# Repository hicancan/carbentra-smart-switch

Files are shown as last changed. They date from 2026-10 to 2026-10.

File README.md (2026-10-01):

# CARBENTRA Switch · 三路智能灯光开关

面向普通照明的三路独立远程通断工程候选。保留本地按键，使用 Wi-Fi 连接 MQTT，蓝牙负责安全配网；计量三路灯具的合计用电。外观参考用户提供的白色圆角三键开关图片，内部结构、电路和固件为独立设计。

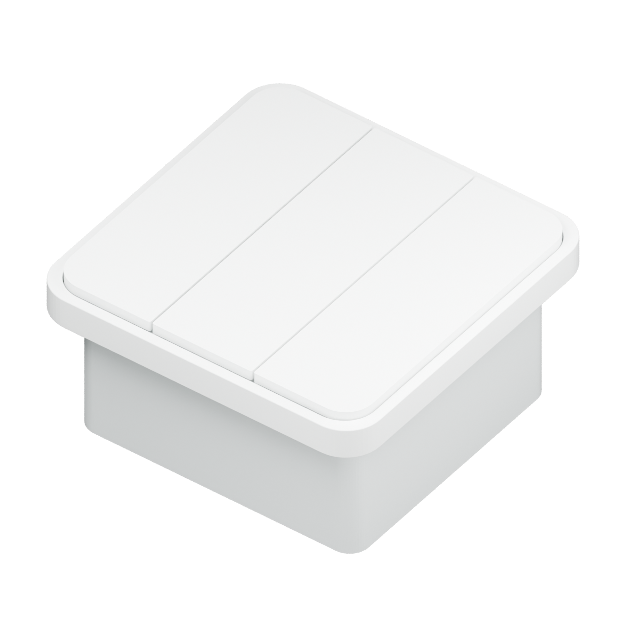
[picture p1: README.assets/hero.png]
Switch 工程外观


## 从这里开始

- **构建验证**：[LOCAL_BUILD.md](LOCAL_BUILD.md)，PowerShell 7 / uv Python 3.12 / MSVC / KiCad 10 / Blender 5.2 / ESP-IDF 5.4.3。
- **改外壳**：`mechanical/` 的可编辑 Blender 源文件与参数化生成脚本
- **改电路**：KiCad 10 打开 `electronics/power.kicad_pro` 或 `electronics/control.kicad_pro`
- **查元器件**：`electronics/bom.csv`、`pinmap.csv`、`mechanical_interface.json`
- **制造与展示**：[GitHub Releases](https://github.com/hicancan/carbentra-smart-switch/releases) 提供 Gerber/钻孔、GLB/STL、图片/PDF/视频与默认禁止吸合的开发固件。
- **继续固件**：[固件说明](firmware/README.md)、[协议与条件](docs/firmware.md)、[实际目标构建报告](firmware/build-report.json)
- **安全修复复验**：[本次固件修复报告](firmware/remediation-report.json)：证书日期配置、实际 ESP32-C3 编译负控与独立 host 证书负控；不代替实物 TLS 握手或现场安全验证
- **了解电气前提**：[电路说明](docs/electronics.md)、[结构说明](mechanical/README.md)

## 已实现的范围

- 三路控制、本地按键防抖、开机先释放、上电OFF；工程构建默认禁止继电器吸合，独立编译放行与逐台commissioning后才允许ON
- 每通道15分钟手动保持、保护/维护/故障守卫，真实本地输入与独立sample序号；网络不能隐式覆盖本地保持
- Wi-Fi 与双向 TLS MQTT 远程命令；时效、序列及幂等处理
- 官方 BLE Security 2 配网，需独立的设备工厂配置；没有内嵌通用密码
- MCP39F511A 串口计量读取、校验与累计能量保存；校准缺失、数据过期或异常时不伪造读数
- 实际 ESP-IDF 5.4.3 / ESP32-C3 目标构建通过，具体结果与源/产物哈希见构建报告

共享设备语义与运行时以 [carbentra-campus-platform](https://github.com/hicancan/carbentra-campus-platform) 的 `packages/iot-contract` 和 `edge` 为唯一实现；lighting-1..3 映射为 relay.1..3，合计电量只计一次。本次 Windows 原生编译、主机回归、ERC/DRC、网络连通、8 mm 隔离与八条主电流路径检查见[验证摘要](verification/local-validation.json)。

可生成的大文件已移出 Git，构建只写指定的外部目录。电路复现边界为原生 KiCad → 严格检查 → 制造输出；旧一次性生成与自动布线工具退入 Git 历史，不承诺重新自动布线得到相同 PCB。

蓝牙在本版本中用于配网，并非另一个直接开关灯协议。计量对象是三路照明合计，不提供单路电量；开关自身待机耗电不在这条分流测量通路内。继电器软件输出状态不等于实际触点或灯具状态的独立回读。

## 尺寸与安装假设

参考图没有确认厂商型号或官方尺寸。本设计提出 86 × 86 mm 面板、9.8 mm 前部突出、74 × 70 × 34 mm 后盒，总包络为 86 × 86 × 43.8 mm。需要根据实际墙腔、螺钉与导线弯曲空间核对，不能当作所有“86底盒”通用安装承诺。

电气方案假设开关盒中具备零线，采用 220–240 V AC、50 Hz 输入。不包含单火线、调光或调色温方案；不需要把灯具回流零线接回该开关盒。

## 使用边界

这是未上电、未安装、未经过实物验证的工程文件。规则检查和成功编译不等同于电气安全、温升、浪涌、EMC、射频、灯具启动冲击或计量精度认证。制造输出不是量产放行文件，需由合格人员完成器件、装配及样机验证。

仅针对普通照明研究，不用于消防应急或其他安全关键照明。远程 OFF 不构成维修隔离；一次保护元件和最终负载能力必须按现场条件验证。

许可证范围见 [LICENSES.md](LICENSES.md)。本地 KiCad 库、SDK、厂商资料继续遵守各自许可；参见 [电路第三方说明](electronics/THIRD_PARTY.md)和[固件第三方说明](firmware/THIRD_PARTY_NOTICES.md)。

本次 Windows 固件与发布回归见 [当前固件验证](verification/current-firmware-validation.json)。打包要求当前来源和实际目标字节一致；历史 CAD/媒体复用独立标注，未重新运行实物、CAD 或渲染验收。

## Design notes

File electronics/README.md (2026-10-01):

# Native editable electronics

Open the control / power `.kicad_pro` projects with KiCad 10.0.5. Schematics, routed boards, rules, local symbol/footprint libraries, BOM, pin maps and mechanical contracts are retained as editable source. These native circuit files are authoritative.

Follow [LOCAL_BUILD.md](../LOCAL_BUILD.md) and `scripts/dev.ps1 -Action electronics -BuildRoot <external-directory>`. The coordinator copies source into a fresh external directory, runs strict ERC/DRC, exports native netlists and independently compares PCB pad connections, then produces schematic PDF, Gerbers, Excellon drills and source-faithful presentation sheets. A nonzero rule check stops the workflow. Generated output and detailed JSON reports live in the build tree and Release bundle.

The export workflow also checks isolated hot/cold copper spacing and eight selected main current paths. These geometrical checks do not establish a load rating or electrical safety certification.

The validated reproducible boundary is native circuit → checks → manufacturing outputs. Earlier one-time ECO, placement-generation and autorouting scripts are retained only in Git history. Their alternate valid routings are not claimed to reproduce the current boards. After deliberate native edits, rerun the whole electronics stage and review the resulting drawings.

Third-party datasheets are linked in `reference-sources.json` and BOM/documentation rather than redistributed. Retained library files preserve their original attribution. See [THIRD_PARTY.md](THIRD_PARTY.md).

Engineering candidate only: no fabricated-board inspection, powered measurements, RF/thermal qualification or manufacturing release is implied.

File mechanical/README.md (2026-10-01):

# SW3 proposed mechanical assembly

This is an independent engineering concept based on the supplied white, rounded three-rocker reference images. No exact manufacturer or model was reliably established. **86 × 86 mm and all housing dimensions are proposed, not manufacturer facts.** The design has no copied logo or certification markings.

## Files

- `carbentra_smart_switch.blend`: neutral, assembled metric source; front is +Z, wall/mounting rear datum Z=0
- `carbentra_smart_switch_animation.blend`: the same real subassemblies with 144 baked frames, 24 fps
- `exports/carbentra_smart_switch.glb`: portable assembly, physical meters
- `exports/*_mm.stl`: structural concept pieces, explicitly millimeter-scaled; not tooling-release files
- `source/build_switch.py` and `source/internal_layout.py`: editable parametric source; component bodies read `electronics/mechanical_interface.json`
- `verification/`: only the minimum file-open, dimensions, gross fit and media checks
- **All images, six views, annotated assembly sheets, SVG/PDF drawings and video are in root `presentation/`**

## Proposed envelope and stack

| Feature | Nominal mm |
|---|---:|
| Face envelope | 86 × 86 |
| Front projection from wall datum | 9.8 |
| Backbox outer envelope | 74 × 70 × 34 |
| Total depth | 43.8 |
| Backbox clear planar cavity | 70 × 66 |
| Main power PCB | 68 × 64 × 1.6, Z -25.6 to -24 |
| Insulating protective partition | Z 0 to +1.8 |
| Isolated control PCB | 76 × 76 × 1, Z +3.2 to +4.2 |
| Momentary rocker main underside / front | Z +7.2 / +9.8 |
| Installer mounting screw centers | X ±30, Y 0; 60 separation |

Suggested initial installation cavity is at least 76 × 72 × 45 mm, but this is **not a compatibility guarantee**. The actual wall box, screw spacing, cable entry and wire bending space must be measured. Do not assume every nominal 86-format wall box accepts this assembly.

The Omron B3U-1000P local switches reach Z +5.8. Molded rocker pushers project 1.4 mm below the main rocker underside; the intended approximately 0.2 mm operating travel still needs button-force and tolerance development.

The real package plan contains three Omron G5Q-1A DC5 relays, RECOM RAC05-05SK/277 isolated supply, MCP39F511A aggregate meter, ISOW7821 isolated interface and ESP32-C3-MINI-1 on the separate cold control PCB. Body envelopes and board coordinates come from the electronics-owned contract, not invented internal parts of the photographed product. Package cosmetic details are simplified; no manufacturer STEP fidelity is claimed.

## Isolation and radio constraints

- Accessible momentary controls are on the isolated cold PCB. A separate insulating partition closes the primary compartment. J3 is on the back of the control board in a modeled isolated-cold protective pocket; both PH8 connectors reserve 10 mm mated height. Eight wires pass sealed individual holes in the pocket floor; the qualified seal/material and harness implementation remain to be developed. The pocket floor top is Z -8.8 and outer bottom Z -10.8. Cable shapes illustrate occupied volume only; the required 5 mm bend radius is not digitally certified
- The installer screws pass through modeled polymer tubes (8 mm OD / 5.5 mm bore), with main PCB side notches and cold PCB clearance holes. Those tubes are a geometry concept, **not proof of reinforced insulation**. Polymer grade, minimum molded wall, tracking resistance, dielectric strength, creepage, clearances and accessible-metal isolation remain safety-review items
- Power board primary/secondary copper zoning, isolation components, fusing, surge protection and electrical slot geometry are owned by the ECAD design. Do not treat the illustration as the copper manufacturing source
- The rim and carrier are nonmetallic. The antenna tip overhangs the control PCB toward +Y; no copper is permitted below its antenna region on any layer. Keep metal, components and installer hardware away per the Espressif antenna guidance; validate the complete wall-box installation, nearby mains wiring and RF behavior on real hardware
- Terminal wire entries are modeled at the recessed backbox upper side. Terminal screw access requires de-energized qualified-installer service with the front/partition removed. A final production design must refine finger protection and service access; never service energized mains
- The selected PSU nominal top is Z -2.2, leaving 2.2 mm physical space below the partition; the maximum MOV envelope leaves 2.0 mm. The rear-mounted C15/C16 capacitors have only 0.6 mm nominal floor clearance and needs tolerance review. Physical space alone does not establish an adequate electrical insulation system

## Status and nonclaims

This is a compact exterior-first engineering proposal with minimum digital checks. It has not undergone mains-powered testing. No load rating, LED inrush capability, energy accuracy, fire rating, insulation certification, RF certification, thermal rating, universal wall-box fit, molding tolerance, button feel or snap-fit life is established. Screw retention, harness termination, terminal access, flame-retardant resin selection, creepage/clearance and standards review need development before any prototype energized testing. Structural STL files are for geometry review and unpowered prototypes only, not a safe live-mains enclosure.

## Reproduction

Use [LOCAL_BUILD.md](../LOCAL_BUILD.md) and `scripts/dev.ps1 -Action mechanical` for geometry/export checks or `-Action render` for presentation. Every action stages source into the specified external build directory. Generated `exports/`, `verification/`, images, PDF and video paths described above exist only in that output tree and the Release bundle, not in the source checkout.

The native assembled and animation `.blend` files stay in this repository. Parameter scripts are editable source. Video uses 37 real 3D assembly states at 1280 × 1280, 144 frames, 24 fps, six seconds, without audio; it is a simulated assembly, not recorded hardware operation. Intermediates remain in the external runtime directory. Source and output hashes record what was checked.

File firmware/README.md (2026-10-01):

# Three-channel smart light switch firmware

ESP32-C3-MINI-1 / ESP-IDF **5.4.3**. Three normally-open relay channels; active-low momentary rocker contacts; secure BLE Wi-Fi provisioning; authenticated MQTT ON/OFF; one isolated MCP39F511A aggregate lighting meter. No dimming, per-channel energy allocation, physical relay feedback or OTA implementation.

The initial image boots all outputs OFF. Physical key sensing works without Wi-Fi, BLE or a broker. Energizing a relay additionally requires the default-OFF build gate and deliberate per-unit factory commissioning; network credentials never grant that release. Local OFF remains available on commissioned units without network service. A key held at boot must first be released. Factory data is intentionally absent from this repository. Missing network credentials disable remote operation; missing or mismatching meter calibration produces null readings.

## Build and host checks

Follow [LOCAL_BUILD.md](../LOCAL_BUILD.md) for the uv + PowerShell + MSVC workflow and pinned ESP-IDF 5.4.3 SDK. The SDK's cJSON compiles with the actual control, meter and command decoder sources. CTest checks commissioning, channel-local holds, maintenance/protection, offline local keys, strict uint64 JSON, replay, meter framing and 2,000 malformed inputs.

See [remediation-report.json](remediation-report.json) for the fresh Linux ESP32-C3
build and TLS remediation evidence. It includes target compile-negative controls
and separately labeled host certificate behavior tests. [build-report.json](build-report.json)
retains the earlier Windows build's original hashes and scope. Development images
and compiler logs are generated outside Git and included in the matching Release.
The build keeps actuation disabled. No board was flashed, calibrated, energized or
physically tested.

## Setup

1. Build the firmware and review [firmware documentation](../docs/firmware.md), the pin map and electronics design. Flash only a safely isolated low-voltage bench target. No live mains commissioning was performed for this deliverable.
2. Prepare a unique device identity, broker client certificate/key, broker CA and per-device BLE Security2 salt/verifier through the operator's approved manufacturing process. Reusable example secrets are not provided. The firmware never prints these values.
3. Store the supplied inputs using `tools/prepare_factory_csv.py` and the official ESP-IDF NVS generator, as documented below. Provision Wi-Fi with Espressif's official BLE provisioning client using Security2, the matching username and unique per-device password. BLE is used for provisioning; MQTT performs remote switching.
4. Configure broker topic ACLs for the device certificate identity. Read its current `state` message, then send a non-retained command with the current boot ID, a strictly increasing decimal sequence and a short boot-relative expiry. Use the acknowledgement to distinguish commanded, duplicate and rejected results. There is no physical-contact verification.
5. A qualified factory process must establish and verify meter calibration and the exact register profile before energy values become available. Firmware does not run automatic calibration or change meter EEPROM/configuration.

See [docs/firmware.md](../docs/firmware.md) for the protocol, factory partition format, calibration units, persistence limitations and official references.

Current Windows firmware/release validation is recorded in `../verification/current-firmware-validation.json`. `remediation-report.json` preserves the earlier Linux run; it is packaged only as historical evidence. See `../LOCAL_BUILD.md` for the source-bound `firmware` action and release checks.

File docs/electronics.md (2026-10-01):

# Smart light switch A: electronics candidate

**Unenergized engineering prototype. Do not install, connect to mains, or treat the Gerbers as a production release.** ERC/DRC and source consistency checks are digital design checks, not product safety, EMC, RF, thermal, LED-inrush, or accuracy certification.

## Scope and interfaces

- Proposed 220–240 V AC, 50 Hz supply **with neutral available in the switch box**; three independent normally-open relay channels
- Wi-Fi remote commands, BLE commissioning, and three local momentary buttons through ESP32-C3-MINI-1-N4X; no dimming
- J1 pins 1–5: **L input, N input, switched L1, switched L2, switched L3**. Lamp neutrals return directly to the supply; they do not need to traverse this switch
- The meter records aggregate lighting energy. It cannot attribute power or Wh to an individual channel, verify a welded relay, or prove a lamp is physically on
- Firmware reports commanded relay state separately from absent physical feedback; uncalibrated, stale, malformed or missing meter readings remain unavailable. See `docs/firmware.md`

## Native deliverables

`electronics/power.kicad_pro`, `.kicad_sch`, `.kicad_pcb`, `.kicad_dru` and corresponding `control.*` are editable KiCad 10 sources. Symbols, footprints and library tables are local and portable. `manifest.json`, `bom.csv`, `pinmap.csv`, and `mechanical_interface.json` describe the same design. The BOM identifies selected major components; commodity passive purchasing substitutions still require voltage, tolerance, temperature, pulse and package review.

- Power PCB: 68 × 64 × 1.6 mm, four copper layers, two open side notches for insulating mounting-screw tubes
- Control PCB: 76 × 76 × 1.0 mm, four copper layers, Ø8.5 mm screw-tube clearances
- Fabrication candidate: `electronics/fabrication/{power,control}/`, including all four copper layers, masks, paste, board outline, Excellon PTH/NPTH drills and placement CSV
- Presentation assets, native schematic PDFs, native SVG plots and drill maps are exclusively under root `presentation/`

No power trace, component or module value is a finished-switch load rating. The **T2 A fuse is a selected protective component, not a certified 2 A product label**. Its time-current curve, prospective fault current, upstream branch protection and enclosure containment must be coordinated in physical qualification.

## Actual circuit

### 1. Protection and cold power

F1 is SCHURTER 3403.0277.23, a time-lag 2 A UMT-H part. RV1 is a thermally protected Littelfuse TMOV14RP275E across the **fused** supply. PS1 is RECOM RAC05-05SK/277, a 5 V/5 W supply selected for reinforced insulation and the manufacturer's OVC III application envelope. A certified component does not certify the assembled wall switch.

The cold 5 V rail supplies three relay coils and a TLV1117LV33DCYR regulator on the control board. The regulator has ceramic input/output capacitors and connected top/inner-layer copper for heat spreading. Wi-Fi peak current, isolated-converter startup, all-coils-on dissipation, brownout behavior and sealed-box temperature rise remain bench tests. No mains neutral is connected to the cold rail.

### 2. Three relay outputs

K1–K3 are Omron G5Q-1A DC5, normally-open contacts driven by AO3400A NMOS devices. Gate series resistors, independent 100 kΩ pull-downs and SS14 coil flyback diodes are implemented. Reset/boot/high-impedance GPIO states therefore bias coils OFF. GPIO0/1/3 control channels 1/2/3.

Generic G5Q contact ratings are not transferred into an LED-load claim. LED driver input capacitance can create severe inrush. Actual lamp types, repetitive make/break endurance, welded-contact faults, arc behavior and temperature rise must be qualified. There is no contact-feedback sensor or safety-disconnect function; the device cannot be used as an isolation switch for servicing.

### 3. Aggregate lighting meter

The current path is:

L_IN → F1 → **H_GND (fused live)** → R7 four-terminal 2 mΩ shunt → H_LOAD → the three relay common contacts → L1/L2/L3.

PS1 branches off before R7, so the intended measured quantity excludes the switch's own electronics consumption. **H_GND is dangerous live potential, not neutral, earth, or accessible digital ground.** Every `H_*` net belongs to that live-referenced meter domain. `C_*` nets belong to the isolated cold domain.

MCP39F511A current input I+ samples the load side of the shunt through 1 kΩ; I− samples its fused-live side through 1 kΩ. V+ receives neutral through four 249 kΩ resistors and a 1 kΩ lower resistor, giving 997:1 nominal attenuation. V− has a matching 1 kΩ return to H_GND. Each channel uses the documented 33 nF input filtering. The 2 mΩ shunt has true separate Kelvin sense pads. Analog decoupling, reference decoupling, RESET/MCLR pull-ups and the COMMONA-to-COMMONB link are present; unused mandatory-NC pins stay floating. The optional external crystal is not fitted; the internal oscillator must be accounted for by the verified factory profile.

For positive lamp consumption both input waveforms have matching negative polarity relative to fused live, yielding positive imported active power. At 2 A, nominal shunt signal is 4 mV RMS, not mains common mode applied to an ADC pin. Validate polarity with a known resistive load and then a nonlinear LED load. Calibration must verify the ADC gain and profile, voltage/current/power/energy scales, frequency, offset and temperature behavior. This design makes **no measured-accuracy claim** and does not rely on zero-calibration defaults.

### 4. Reinforced meter bridge

U3 is **ISOW7821DWER**, a two-direction digital isolator with integrated isolated power. Cold 3.3 V enters VCC/GND1. SEL is tied to hot GND2 for a 3.3 V isolated output. UART idle-high default is intentionally selected by the non-F device variant. The manufacturer's specified working insulation voltage is distinct from its short-duration withstand test; the selected part lists 1000 V RMS working insulation and >8 mm package clearance/creepage.

The local footprint follows the manufacturer's **HV/isolation pad option**, 9.75 mm row-center spacing and 1.65 mm pad length, leaving 8.1 mm between facing copper lands. Bulk input capacitance exceeds the isolated-side output capacitance by more than 100 µF. The hot and cold grounds are not joined, including through the harness, programming pads or inner layers.

### 5. Radio and local control

U1 is ESP32-C3-MINI-1-N4X. GPIO4/5/6 are active-low local buttons, each with external 10 kΩ pull-up and 10 nF capacitor. GPIO7 is isolated-meter UART RX; GPIO10 is TX. GPIO2/8/9 boot straps are not used to drive relays. EN has external pull-up and capacitor. Service pogo pads expose cold ground, 3.3 V, EN, BOOT, UART0 and native USB signals; no USB connector or mains-referenced debug port is exposed to the user.

The module uses the manufacturer's 53-pin land pattern, a top-edge antenna overhang, and an all-layer copper exclusion below the antenna area. The enclosure carrier is polymer. RF matching through the actual plastic/rocker stack, conducted/radiated coexistence, range, interference and regulatory testing remain unperformed. Do not infer radio performance from renderings.

### 6. Cold harness and assembly

J2 and J3 are keyed JST PH 8-way connectors with the same pin map:

1. C_5V
2. C_GND
3. C_3V3
4. C_RELAY1
5. C_RELAY2
6. C_RELAY3
7. C_UART_TX
8. C_UART_RX

J3 is on the control board's **bottom** face, with a local cold-side pocket through the solid partition. The mechanical file budgets the mated connector, not just the bare header. C15/C16 are on the power board rear face and have only 0.6 mm nominal rear-floor clearance; lead trimming, capacitor tolerances, board bow and assembly stack-up must be checked. The 17 major package envelopes in `mechanical_interface.json` are maximum or conservative bodies, not detailed vendor STEP models.

## Insulation assumptions and limits

The final mains spacing assumption is **220–240 V AC nominal, overvoltage category III, 4 kV rated impulse, pollution degree 2, altitude ≤2000 m, uncoated FR4**. The initial 2 mm routing screen was not a justified fixed-installation qualification and is superseded. Native custom rules now require **3 mm** between raw input line, the unattenuated neutral or a switched output and other hot copper that may sit at full mains differential. Hot-domain 3.3 V circuitry retains a 0.2 mm low-voltage rule; graded divider nodes and certified component internals are not blindly treated as independent full-mains conductors.

The whole hot-to-cold PCB copper target is **8 mm**. The router enforces it on the XY projection across every copper layer, and a separate conservative geometric checker covers pads, tracks, vias and otherwise unconnected isolator-side leads. This is stronger than only comparing same-layer copper. It does not assess 3D paths around relay bodies, solder contamination, creepage over supports, screws, wiring, enclosure seams, pollution, material CTI, fire containment or solid-insulation thickness. The final product standard and its applicable creepage/clearance rules still require qualified review. No conformal-coating credit is assumed.

The primary basis is TI's *Demystifying Clearance and Creepage Distance for High-Voltage End Equipment*, especially its IEC 60664-1 4 kV example and altitude treatment. Required creepage also depends on actual working voltage and material group; specify and verify laminate CTI rather than assuming every FR4 grade is equivalent.

## Verification and reproduction

Machine-readable evidence is in `electronics/verification/`:

- Both schematics: actual KiCad ERC output
- Both boards: actual KiCad DRC output, including unconnected-item lists
- `validation.json`: all native schematic nodes compared with PCB pad nets, separate by board, and eight-pin cold harness agreement
- `isolation_xy.json`: independent all-layer conservative hot/cold geometry check
- `load_paths.json`: native connectivity of all eight main lamp-current paths after removing every trace narrower than 1.2 mm and every via smaller than 1.6 mm. The fuse-to-shunt path is an explicit current trunk; narrow hot-reference branches do not carry the intended lamp current. This is no temperature-rise, surge or load-rating validation
- `presentation.json`: SHA-256 of native files used for unchanged-source SVG/PNG generation

Follow [LOCAL_BUILD.md](../LOCAL_BUILD.md) and run the PowerShell electronics stage. It checks authoritative native sources and writes all exports to an explicit external build tree. One-time circuit-generation/autorouting scripts were retired to Git history. The report filenames listed above exist in that generated tree or Release bundle. No hardware is energized.

### Manufacturing candidate notes

Suggested stack-ups (fabricator must approve dielectric construction and tolerances):

- Power 1.60 mm: F.Cu 70 µm / prepreg 0.20 mm / In1 35 µm / core 0.99 mm / In2 35 µm / prepreg 0.20 mm / B.Cu 70 µm
- Control 1.00 mm: F.Cu 35 µm / prepreg 0.18 mm / In1 18 µm / core 0.534 mm / In2 18 µm / prepreg 0.18 mm / B.Cu 35 µm
- Fine-pitch meter escape uses 0.13 mm tracks and 0.45/0.20 mm via diameter/drill. Ordinary routing is wider. Main candidate current routes use 1.2 mm tracks and, where needed, 1.6/0.8 mm vias; these dimensions do not establish a load rating
- Relay and terminal PTH lands are 2.0 mm on 1.3 mm drills; verify the 0.35 mm nominal annulus against hole and registration tolerances
- Copper masks and inner-layer clearances must survive fabricator CAM review. The board outlines include open power-board mounting notches; do not substitute plated mounting holes
- No soldermask, coating, component approval or fuse value is a substitute for complete end-product qualification

## Primary references

- [Microchip MCP39F511A datasheet](https://ww1.microchip.com/downloads/en/DeviceDoc/MCP39F511A-Data-Sheet-20006044A.pdf), pin table, application circuit, protocol and calibration
- [Microchip ADM00667 reference board](https://ww1.microchip.com/downloads/aemDocuments/documents/OTH/ProductDocuments/UserGuides/MCP39F511A-Demo-Board-User-Guide-50002770A.pdf)
- [TI ISOW7821 datasheet](https://www.ti.com/lit/ds/symlink/isow7821.pdf), insulation table, HV land pattern and input bulk capacitance guidance
- [RECOM RAC05-K/277 datasheet](https://recom-power.com/pdf/Powerline_AC-DC/RAC05-K_277.pdf)
- [Omron G5Q datasheet](https://components.omron.com/sites/default/files/datasheet_pdf/J155-E1.pdf)
- [Espressif ESP32-C3-MINI-1 datasheet](https://documentation.espressif.com/esp32-c3-mini-1_datasheet_en.pdf)
- [Vishay WSK2512 datasheet](https://www.vishay.com/docs/30108/wsk2512.pdf)
- [SCHURTER UMT-H datasheet](https://www.schurter.com/en/datasheet/typ_UMT-H.pdf)
- [Littelfuse TMOV datasheet](https://www.littelfuse.com/assetdocs/varistors-tmov-datasheet?assetguid=bd475732-1071-4352-b8aa-f78b0007eb05)
- [TI TLV1117LV datasheet](https://www.ti.com/lit/ds/symlink/tlv1117lv.pdf)
- [Omron B3U datasheet](https://components.omron.com/us-en/system/files/2023-01/datasheet_pdf/A162-E1.pdf)
- [TI clearance and creepage design seminar](https://www.ti.com/lit/ml/slup419/slup419.pdf)

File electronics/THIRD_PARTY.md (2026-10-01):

# Component and CAD library attribution

Local stock KiCad symbols and footprints originate from the KiCad libraries:
- https://gitlab.com/kicad/libraries/kicad-symbols
- https://gitlab.com/kicad/libraries/kicad-footprints

KiCad library content uses CC BY-SA 4.0 with the KiCad Libraries Exception: https://www.kicad.org/libraries/license/ . Local library identifiers and existing attribution are retained. Project-level hardware licensing does not overwrite the library license or exception.

Custom package outlines implement dimensions from manufacturer drawings. The BOM, pin map and docs/electronics.md identify selected parts and primary datasheets. Manufacturer names identify components, not endorsement or certification. Vendor PDFs/HTML snapshots are no longer redistributed: reference-sources.json preserves their original hashes and source links.

Firmware SDK/runtime notices are in ../firmware/THIRD_PARTY_NOTICES.md. No production credentials or private manufacturer application are provided.

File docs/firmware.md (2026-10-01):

# Firmware and remote-control contract

## Implemented scope

Three independent lighting ON/OFF channels use normally-open relay drives. Three active-low, momentary local contacts toggle their corresponding commanded state after35ms of stable debounce. The contact must be released before its first accepted press after reboot. Maintained/latching rocker contacts need a different local-control policy and are not assumed by this implementation. Offline switching does not depend on network initialization. Reset starts all outputs OFF; no previous ON state is restored.

Wi-Fi carries authenticated MQTT control and state. BLE provides Espressif's official Wi-Fi provisioning service using Security2 (SRP6a and AES-GCM), with per-unit salt/verifier loaded from factory NVS. Security0/1 are disabled; no plaintext provisioning fallback or shared password is compiled in. BLE stops after successful provisioning. Changing provisioned Wi-Fi requires a deliberate service operation on the Wi-Fi NVS partition; the command protocol has no remote credential-reset or factory-reset operation.

The three logical switch channels share one aggregate meter covering the sum of their lighting loads. Future campus integration must register three controllable channels plus one parent aggregate energy boundary, without fabricating per-channel energy or counting the aggregate three times. The shared campus Edge adapter maps physical channel IDs lighting-1..3 to canonical relay.1..3 and preserves the single aggregate energy boundary.

## Cold-domain GPIO contract

| Function | ESP32-C3 GPIO | Electrical interpretation |
| --- | ---: | --- |
| Relay1 / Relay2 / Relay3 | 0 / 1 / 3 | Active-high NMOS drives, external100k pulldowns |
| Key1 / Key2 / Key3 | 4 / 5 / 6 | Active-low, external10k pullups and10nF |
| Meter UART RX / TX | 7 / 10 | UART1,9600baud,8N1, isolated channel |
| Reserved boot straps | 2 / 8 / 9 | No application output use |
| USB | 18 / 19 | Reserved |
| Service UART0 | 20 / 21 | Console; firmware does not log secrets |

GPIO latch levels are cleared before enabling output direction. External pulldowns cover reset/boot-ROM intervals. Software state and an electrical GPIO request do not prove relay-contact closure, load current or lamp illumination. Acknowledgements explicitly have `physical_verification:false`; per-channel state has `physically_verified_on:null`.

The MCP39F511A and its analog input circuit are in the hot mains domain. UART crosses the TI ISOW7821 isolation boundary; its isolated supply powers the meter side. The cold controller has no isolation-readiness GPIO and cannot certify insulation, creepage, clearance, relay inrush suitability or safe mains conditions. Calibration/readback only addresses measurement configuration. Firmware is not a substitute for the electronics safety review or physical commissioning.

## MQTT wire protocol

All connections use `mqtts://hostname[:port]`, a supplied CA trust anchor, server-hostname validation and a supplied client certificate/private key. Firmware rejects insecure MQTT URIs and never enables skip-CN checks. Broker ACLs must bind the client identity to its own namespace; authenticated controller clients may publish only to the intended device command topics. SNTP establishes usable wall time for certificate checks before MQTT starts. Command freshness uses a boot-relative clock and does not trust an arbitrary controller wall clock.

Both `sdkconfig.defaults` and the maintained `sdkconfig` require
`CONFIG_MBEDTLS_HAVE_TIME=y` and `CONFIG_MBEDTLS_HAVE_TIME_DATE=y`.
`main/tls_policy.h`, compiled in the actual network translation unit, rejects
missing ESP-IDF options, missing effective mbedTLS time/date macros, or insecure
TLS verification. The target coordinator checks the generated configuration too.

**Time-source threat boundary:** the current bootstrap uses unauthenticated SNTP
(`pool.ntp.org`) and waits for a wall clock at least 2025-01-01. This is a plausibility
gate, not authenticated time or rollback protection. Date validation is against
that system clock; an attacker able to manipulate SNTP can affect certificate
validity decisions. CA and hostname checks remain required, but they do not
authenticate the SNTP clock. Deploy only where that time-source/network assumption
is acceptable; a hostile-time threat model requires a separately reviewed signed
time/bootstrap design before release. Switch does not inherit Plug's signed-time
implementation. No missing-time or date-check-disabled fallback is provided.

Topics:

- `carbentra/switch/<device_id>/command`: controller→device, QoS1, **not retained**
- `carbentra/switch/<device_id>/ack`: device→controller, QoS1, not retained
- `carbentra/switch/<device_id>/state`: device→controller, latest retained snapshot every2s while connected
- `carbentra/switch/<device_id>/availability`: retained online/offline, MQTT last will

A command is an object with exactly these six properties. The example values are illustrative protocol data, not executable commissioning instructions:

```json
{"id":"request-42","boot_id":"0123456789abcdef0123456789abcdef","seq":"42","channel":2,"on":true,"expires_uptime_ms":"125000"}
```

`boot_id` must equal the current state message's32-hex-character boot ID. Firmware obtains fresh128-bit random data from the SDK's explicitly enabled boot-time entropy source before Wi-Fi starts. `seq` and `expires_uptime_ms` are unsigned decimal strings, avoiding JSON double precision loss. Channel is the integer1,2 or3; on is an actual boolean. ID accepts1..48 ASCII alphanumerics, hyphens and underscores. Maximum payload768bytes. Unexpected/duplicate fields, embedded NUL, malformed fragments, invalid types, retained commands and oversized payloads cannot actuate a relay.

Expiry must be strictly after current uptime and at most30s ahead. Controllers should obtain fresh uptime from state and allow transport latency. Sequences increase globally per device boot; coordinate multiple controller clients through one sequence allocator. The last16 accepted command IDs are cached. An identical retry returns `duplicate` without reapplying the output, even if a local key subsequently changed it. Reusing an ID with different content returns `id_conflict`. An evicted old sequence is still rejected. New boot IDs invalidate commands from earlier sessions; the first command in a boot can start at sequence1. No acknowledgement claims measured physical success.

Example acknowledgement fields are device_id, boot_id, id, seq, channel, result, uptime_ms and physical_verification:false. Results are commanded, duplicate, invalid_command, wrong_boot, expired, stale_sequence or id_conflict. A malformed request without a valid ID may receive an invalid_command acknowledgement without id/seq/channel. Rejected retained/oversized/wrong-topic input is discarded. The next state snapshot reports all three current commanded states.

## Meter parsing and calibration

The driver implements MCP39F511A SSI requests:0xA5 header, complete-frame byte count, big-endian address pointer,0x4E register read, and modulo256 sum checksum. A read response must have0x06 ACK, exact count, complete payload and valid checksum. Register data is little-endian. Read blocks never exceed32data bytes.0x15 NAK,0x51 checksum failure, bad lengths, truncation and timeouts cannot become valid samples. The documented unframed0x5A identification probe must return0x15,0x04 before the factory profile is trusted.

Measurement reads cover0x0002..0x001D and import/export active counters0x001E..0x002D. Active power direction comes from System Status SIGN_PA, rather than treating the unsigned magnitude as signed. There is no per-channel energy estimate. UART is polled about once per second; values become unavailable after failure or a5s freshness limit.

A factory calibration record contains an immutable per-unit calibration ID, verified output-unit scales and exactly146bytes from registers0x0050..0x00E1. Firmware compares the full snapshot at startup and every60s, and requires AC mode, live ADCs, energy accumulation enabled, two-wire operation and9600baud. A mismatch, missing record or wrong device identity yields null physical values. The record must be captured after the qualified process has set the correct current polarity,50Hz calibration/reference and gain/range values, saved them and verified readback. The final electronics reference uses a Vishay WSK25122L000FEA2mΩ four-terminal shunt,997:1 voltage divider and the internal4MHz oscillator. Current and voltage input polarities are both negative for positive import in the selected topology, so their product must be verified positive by the fixture. The PSU branch precedes the shunt and is excluded from aggregate lighting energy. These analog values are not hardcoded as unverified firmware conversion constants. Factory default values or the datasheet's nominal resolution are not a calibration result.

Scale fields are positive integer microvolts per voltage count, microamps per current count, milliwatts per active-power count and milliwatt-hours per energy count. Their accepted range is1..1,000,000. The datasheet describes a default1mWh energy step; the actual record must confirm the configured system. The firmware performs no calibration/configuration writes or energy-counter EEPROM writes. No accuracy percentage or regulatory energy-billing suitability is claimed.

## Persistent energy semantics

The firmware adds only observed, monotonic import-counter deltas with known scale. It does not integrate estimated power or invent energy across reboot, lost communication, counter rollback or rejected jumps. The first sample after each such interruption establishes a new baseline. An internal50kW plausibility ceiling rejects corrupted jumps; it is not a hardware load or relay rating.

Known energy is checkpointed in a separate `energy` NVS partition every60s using a versioned binary format, profile fingerprint and CRC32. After an unexpected power loss, up to60s of newly accumulated known energy can be absent from the saved lower bound, in addition to unknown boot/gap intervals. Telemetry labels it `energy_quality:"partial_lower_bound"`, includes unknown_intervals and checkpoint_interval_seconds, and represents exact known_energy_wh as a decimal string. Missing calibration/storage integrity yields null. A valid measured zero is allowed only within this qualified known-energy context.

A corrupt checkpoint or changed calibration fingerprint is not silently erased or assigned to a new meter. Energy accumulation is disabled pending a deliberate service workflow that archives prior records and provisions a new energy epoch. NVS initialization failures do not erase data automatically. Storage failures are exposed by persistent_storage_ok:false. The flash endurance/checkpoint interval must be validated for the physical product's required service life.

## Factory data and setup

The custom4MiB partition table allocates Wi-Fi NVS, a read-only-by-application `factory` NVS partition, a2.5MiB app slot, and separate energy NVS. It has no OTA partition. Credentials are absent from the source tree. The factory namespace is `switchcfg` (9characters); energy namespace is `energy`.

Prepare a private JSON specification outside Git with device_id, mqtt_uri and paths to prov_salt (16binary bytes), prov_verifier (384binary bytes), ca_pem, client_cert and client_key. Use unique SRP credentials and a unique broker client identity for every device. Espressif's official `tools/esp_prov/esp_prov.py` supports Security2 credential generation through an operator-controlled manufacturing process; this deliverable did not generate or provision credentials. Do not place passwords in shell history or logs.

Optional `calibration` contains id, profile_file and voltage_uv/current_ua/power_mw/energy_mwh. Omit it for uncalibrated logic bring-up; physical values will remain null. The preparation helper validates file lengths and profile fields, then emits a private CSV containing file references. It does not generate secrets, flash, connect or transmit.

```sh
python firmware/tools/prepare_factory_csv.py /private/unit-spec.json /private/unit-factory.csv
python "$IDF_PATH/components/nvs_flash/nvs_partition_generator/nvs_partition_gen.py" generate \
  /private/unit-factory.csv /private/unit-factory.bin 0x10000
```

The factory binary must be installed at its explicit partition offset0x10000 by an authorized technician, together with the ordinary SDK build outputs. An ordinary `idf.py flash` does not supply factory credentials. Use official Espressif provisioning clients with Security2 and the matching username/password supplied separately to the owner; no credential-bearing QR is emitted to logs. Broker ACLs and certificate issuance belong to the operator, not this repository.

The default bench build does not burn security eFuses, enable irreversible Secure Boot, or provision flash-encryption keys. Factory credentials are therefore physically readable unless a product-specific encrypted-NVS/flash-encryption and debug-access policy is provisioned. Network transport/authentication is implemented; physical extraction resistance is not claimed by this default build. Deploying that security policy requires the appropriate authorized manufacturing procedure.

## Verification and remaining physical work

Host regression groups compile the real C core and cJSON decoder with strict warnings and CTest on Windows. They cover offline keys/held-key boot, debounce, all channel bounds, maximum64-bit sequence and overflow, replay/idempotency/conflicts, old-boot rejection, expiry, official meter request bytes, little-endian decoding, checksum/length errors, import/export sign, missing intervals, monotonic delta handling, checkpoint corruption/profile mismatch, strict JSON and2,000 malformed-input cases. Current Windows evidence does not claim UBSan or LeakSanitizer. Earlier Linux sanitizer results remain historical.

Target build status is recorded in firmware/build-report.json when compilation completes. No ESP32 board, relay, lamp, radio link, broker deployment, live credentials or mains meter was exercised here. Hardware UART timing, polarity, real calibration, RF coexistence, power-loss behavior, contact/inrush performance and physical safety remain bench/engineering validation tasks. Generated images and presentation assets are owned by the root presentation workflow, not firmware.

The TLS remediation has three separate verification levels: the maintained
`tests/check_tls_config.py` regression checks both configuration files and compiles
positive/negative fixtures against the actual guard; `tests/check_certificate_policy.py`
exercises a separately compiled **host** mbedTLS verifier with valid, expired,
not-yet-valid, wrong-CA and wrong-hostname synthetic certificates; a pinned ESP-IDF
target build/real MQTT handshake remains a separate gate. The host library's date
behavior must never be reported as ESP-IDF target behavior. Existing checked-in
build/source manifests describe their original source hashes and predate this
remediation until a new pinned target build is recorded.

## Primary references

- [ESP-IDF5.4.3 ESP32-C3 documentation](https://docs.espressif.com/projects/esp-idf/en/v5.4.3/esp32c3/index.html)
- [ESP-IDF5.4.3 provisioning example/source](https://github.com/espressif/esp-idf/tree/v5.4.3/examples/provisioning/wifi_prov_mgr)
- [ESP-IDF5.4.3 MQTT client](https://docs.espressif.com/projects/esp-idf/en/v5.4.3/esp32c3/api-reference/protocols/mqtt.html)
- [MCP39F511A datasheet DS20006044A](https://ww1.microchip.com/downloads/aemDocuments/documents/OTH/ProductDocuments/DataSheets/MCP39F511A-Data-Sheet-20006044A.pdf), sections4,5.6,6and9
- [MCP39F511A demonstration-board user guide](https://ww1.microchip.com/downloads/aemDocuments/documents/OTH/ProductDocuments/UserGuides/MCP39F511A-Demo-Board-User-Guide-50002770A.pdf)

## Classroom control upgrade (2026-10-01)

The six-property command remains unchanged. A genuine debounced local key press records its channel, event sequence, uptime and result, and establishes a channel-local manual hold (default 900,000 ms; factory bounds 1..3,600,000 ms). Commands to another channel are independent. Remote ON and OFF are rejected during manual hold, maintenance or a protected channel policy. No remote override flag is accepted. Hold expiry permits future commands but does not itself switch a relay. Exact accepted retries still return duplicate without replaying the action.

Protected channels reject automation while retaining physical local control. Maintenance blocks energizing and forces all commanded states OFF. A GPIO write error latches a software fault and requests all outputs OFF; this does not prove mains disconnection. No electronic overcurrent/overtemperature protection or independent feedback sensor has been invented. Physical protection and qualification remain separate release requirements.

CONFIG_CARBENTRA_SWITCH_ALLOW_ACTUATION defaults OFF. The application also requires explicit per-unit factory commissioned=true before any local or remote ON. Factory values maintenance, protected_mask (bits0..2) and manual_hold_ms are read once at boot; missing values use safe defaults. Merely supplying BLE/MQTT credentials, calibration data or compiling this source does not commission hardware. No release build enabling actuation is produced here.

State adds schema_version=1, device_type=smart_switch and sample_seq (monotonic uint64 decimal string, distinct from last_seq command replay counter). Each state publication gets a sequence; boot_id separates restarts. Each channel carries channel_id lighting-1..3, control_mode auto/manual/maintenance/protected, manual_hold_until_uptime_ms, commanded_on, and physically_verified_on=null with feedback_quality=unavailable_no_independent_sensor. Root fields include actuation_enabled, fault_latched, maintenance, protected_channel_mask and last_local_input {channel,event_seq,uptime_ms,pressed,result}. Event sequence 0 means no press observed. A periodic snapshot does not turn a retained local-input record into a new event; consumers deduplicate by boot_id/event_seq.

Additional rejection results: manual_hold, maintenance, protected, not_commissioned, fault_latched. Aggregate energy remains a partial lower bound and must not be allocated to individual channels.

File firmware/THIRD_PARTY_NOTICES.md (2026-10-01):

# Build and binary component notices

The target is built against ESP-IDF v5.4.3 commit ea1c174c1cbb7348bd8ba0ff1eb306246938dd80. The SDK and recursive submodules remain external tool installations. The exact SDK source is available at https://github.com/espressif/esp-idf/tree/ea1c174c1cbb7348bd8ba0ff1eb306246938dd80 . Preserve the SDK's component licenses when rebuilding or redistributing an image.

Bundled license texts in licenses/ cover ESP-IDF (Apache-2.0), cJSON (MIT), Mbed TLS (Apache-2.0), Apache NimBLE with NOTICE, TinyCrypt (BSD), lwIP (BSD), FreeRTOS (MIT), and the individual Newlib runtime notices. The Espressif Wi-Fi, PHY, coexistence and ESP32-C3 Bluetooth library licenses are copied verbatim from the pinned SDK; those libraries are not project-owned source.

Compiler runtime portions remain covered by their own notices and the GCC Runtime Library Exception. This ledger records the principal directly used components, not a formal exhaustive licensing audit. SDK subcomponents retain their SPDX headers and original source notices. Project-level licenses do not replace them.

Development firmware has relay actuation disabled. No private key, client certificate, Security2 secret, calibration record or per-unit commissioning record is included. Public synthetic test fixtures must not be used as production credentials.

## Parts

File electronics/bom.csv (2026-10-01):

Reference | Board | Value | Manufacturer part / specification | Footprint | Primary source | Side
J1 | power | L N L1 L2 L3 | Phoenix Contact MKDS 1,5/5-5,08 | TerminalBlock_Phoenix:TerminalBlock_Phoenix_MKDS-1,5-5-5.08_1x05_P5.08mm_Horizontal | https://www.phoenixcontact.com/en-us/products/pcb-terminal-block-mkds-15-5-508-1715750 | F
F1 | power | T2A 277VAC / 1500A BC | SCHURTER 3403.0277.23 | Switch:UMT_H | https://www.schurter.com/en/datasheet/typ_UMT-H.pdf | F
PS1 | power | RAC05-05SK/277 | RAC05-05SK/277 | Switch:RAC05_05SK_277 | https://recom-power.com/pdf/Powerline_AC-DC/RAC05-K_277.pdf | F
RV1 | power | TMOV14RP275E | Littelfuse TMOV14RP275E (thermal protected) | Switch:TMOV14 | https://www.littelfuse.com/products/overvoltage-protection/varistors/thermally-protected/tmov | F
K1 | power | G5Q-1A DC5 | G5Q-1A DC5 | Relay_THT:Relay_SPST_Omron-G5Q-1A | https://components.omron.com/sites/default/files/datasheet_pdf/J155-E1.pdf | F
Q1 | power | AO3400A | AO3400A | Package_TO_SOT_SMD:SOT-23 | https://www.aosmd.com/sites/default/files/res/datasheets/AO3400A.pdf | F
R1 | power | 100R | 0603 1% 100R | Resistor_SMD:R_0603_1608Metric |  | F
R4 | power | 100k | 0603 1% 100k | Resistor_SMD:R_0603_1608Metric |  | F
D1 | power | SS14 | SS14 | Diode_SMD:D_SMA | https://www.vishay.com/docs/88746/ss12.pdf | B
K2 | power | G5Q-1A DC5 | G5Q-1A DC5 | Relay_THT:Relay_SPST_Omron-G5Q-1A | https://components.omron.com/sites/default/files/datasheet_pdf/J155-E1.pdf | F
Q2 | power | AO3400A | AO3400A | Package_TO_SOT_SMD:SOT-23 | https://www.aosmd.com/sites/default/files/res/datasheets/AO3400A.pdf | F
R2 | power | 100R | 0603 1% 100R | Resistor_SMD:R_0603_1608Metric |  | F
R5 | power | 100k | 0603 1% 100k | Resistor_SMD:R_0603_1608Metric |  | F
D2 | power | SS14 | SS14 | Diode_SMD:D_SMA | https://www.vishay.com/docs/88746/ss12.pdf | B
K3 | power | G5Q-1A DC5 | G5Q-1A DC5 | Relay_THT:Relay_SPST_Omron-G5Q-1A | https://components.omron.com/sites/default/files/datasheet_pdf/J155-E1.pdf | F
Q3 | power | AO3400A | AO3400A | Package_TO_SOT_SMD:SOT-23 | https://www.aosmd.com/sites/default/files/res/datasheets/AO3400A.pdf | F
R3 | power | 100R | 0603 1% 100R | Resistor_SMD:R_0603_1608Metric |  | B
R6 | power | 100k | 0603 1% 100k | Resistor_SMD:R_0603_1608Metric |  | B
D3 | power | SS14 | SS14 | Diode_SMD:D_SMA | https://www.vishay.com/docs/88746/ss12.pdf | B
U2 | power | MCP39F511A-E/MQ | MCP39F511A-E/MQ | Package_DFN_QFN:QFN-28-1EP_5x5mm_P0.5mm_EP3.25x3.25mm | https://ww1.microchip.com/downloads/en/DeviceDoc/MCP39F511A-Data-Sheet-20006044A.pdf | B
U3 | power | ISOW7821DWER | ISOW7821DWER | Switch:ISOW7821_DWE | https://www.ti.com/lit/ds/symlink/isow7821.pdf | F
R7 | power | 2mR 4-terminal Kelvin | WSK25122L000FEA | Resistor_SMD:R_Shunt_Vishay_WSK2512_6332Metric_T2.21mm | https://www.vishay.com/docs/30108/wsk2512.pdf | B
R8 | power | 1k | 0603 1% 1k | Resistor_SMD:R_0603_1608Metric |  | B
R9 | power | 1k | 0603 1% 1k | Resistor_SMD:R_0603_1608Metric |  | B
R10 | power | 1k | 0603 1% 1k | Resistor_SMD:R_0603_1608Metric |  | B
R11 | power | 249k | 1206 1% 249k | Resistor_SMD:R_1206_3216Metric |  | B
R12 | power | 249k | 1206 1% 249k | Resistor_SMD:R_1206_3216Metric |  | B
R13 | power | 249k | 1206 1% 249k | Resistor_SMD:R_1206_3216Metric |  | B
R14 | power | 249k | 1206 1% 249k | Resistor_SMD:R_1206_3216Metric |  | B
R15 | power | 1k | 0603 1% 1k | Resistor_SMD:R_0603_1608Metric |  | B
R16 | power | 10R | 0603 1% 10R | Resistor_SMD:R_0603_1608Metric |  | B
R17 | power | 10k | 0603 1% 10k | Resistor_SMD:R_0603_1608Metric |  | B
R18 | power | 10k | 0603 1% 10k | Resistor_SMD:R_0603_1608Metric |  | B
C1 | power | 33n | 0603 X7R 16V 33n | Capacitor_SMD:C_0603_1608Metric |  | B
C2 | power | 33n | 0603 X7R 16V 33n | Capacitor_SMD:C_0603_1608Metric |  | B
C3 | power | 33n | 0603 X7R 16V 33n | Capacitor_SMD:C_0603_1608Metric |  | B
C4 | power | 33n | 0603 X7R 16V 33n | Capacitor_SMD:C_0603_1608Metric |  | B
C5 | power | 1u | 0603 X7R 16V 1u | Capacitor_SMD:C_0603_1608Metric |  | B
C6 | power | 100n | 0603 X7R 16V 100n | Capacitor_SMD:C_0603_1608Metric |  | B
C7 | power | 100n | 0603 X7R 16V 100n | Capacitor_SMD:C_0603_1608Metric |  | B
C8 | power | 100n | 0603 X7R 16V 100n | Capacitor_SMD:C_0603_1608Metric |  | B
C9 | power | 100n | 0603 X7R 16V 100n | Capacitor_SMD:C_0603_1608Metric |  | B
C10 | power | 100n | 0603 X7R 16V 100n | Capacitor_SMD:C_0603_1608Metric |  | B
C11 | power | 10u | 0805 X7R 16V 10u | Capacitor_SMD:C_0805_2012Metric |  | F
C12 | power | 100n | 0603 X7R 16V 100n | Capacitor_SMD:C_0603_1608Metric |  | F
C13 | power | 10u | 0805 X7R 16V 10u | Capacitor_SMD:C_0805_2012Metric |  | B
C14 | power | 100n | 0603 X7R 16V 100n | Capacitor_SMD:C_0603_1608Metric |  | B
C15 | power | 220u 6.3V | Panasonic EEE-FT0J221AR | Capacitor_SMD:CP_Elec_6.3x5.8 |  | B
C16 | power | 100u 10V | Panasonic EEE-FT1A101AR | Capacitor_SMD:CP_Elec_6.3x5.8 |  | B
J2 | power | COLD LINK / JST-PH8 | COLD LINK / JST-PH8 | Connector_JST:JST_PH_B8B-PH-K_1x08_P2.00mm_Vertical | https://www.jst-mfg.com/product/pdf/eng/ePH.pdf | F
J3 | control | COLD LINK / JST-PH8 | COLD LINK / JST-PH8 | Connector_JST:JST_PH_B8B-PH-K_1x08_P2.00mm_Vertical | https://www.jst-mfg.com/product/pdf/eng/ePH.pdf | B
U1 | control | ESP32-C3-MINI-1-N4X | ESP32-C3-MINI-1-N4X | Switch:ESP32_C3_MINI_1 | https://documentation.espressif.com/esp32-c3-mini-1_datasheet_en.pdf | F
R30 | control | 10k | 0603 1% 10k | Resistor_SMD:R_0603_1608Metric |  | F
R31 | control | 10k | 0603 1% 10k | Resistor_SMD:R_0603_1608Metric |  | F
R32 | control | 10k | 0603 1% 10k | Resistor_SMD:R_0603_1608Metric |  | F
R33 | control | 10k | 0603 1% 10k | Resistor_SMD:R_0603_1608Metric |  | F
C30 | control | 1u | 0603 X7R 16V 1u | Capacitor_SMD:C_0603_1608Metric |  | F
C31 | control | 10u | 0805 X7R 16V 10u | Capacitor_SMD:C_0805_2012Metric |  | F
C32 | control | 100n | 0603 X7R 16V 100n | Capacitor_SMD:C_0603_1608Metric |  | F
U4 | control | TLV1117LV33DCYR | TLV1117LV33DCYR | Package_TO_SOT_SMD:SOT-223-3_TabPin2 | https://www.ti.com/lit/ds/symlink/tlv1117lv.pdf | F
C33 | control | 22u | 1206 X7R 16V 22u | Capacitor_SMD:C_1206_3216Metric |  | F
C34 | control | 22u | 1206 X7R 16V 22u | Capacitor_SMD:C_1206_3216Metric |  | F
C35 | control | 100n | 0603 X7R 16V 100n | Capacitor_SMD:C_0603_1608Metric |  | F
TP1 | control | C_GND | Factory pogo pad | TestPoint:TestPoint_Pad_D1.5mm |  | F
TP2 | control | C_3V3 | Factory pogo pad | TestPoint:TestPoint_Pad_D1.5mm |  | F
TP3 | control | C_EN | Factory pogo pad | TestPoint:TestPoint_Pad_D1.5mm |  | F
TP4 | control | C_BOOT | Factory pogo pad | TestPoint:TestPoint_Pad_D1.5mm |  | F
TP5 | control | C_U0RX | Factory pogo pad | TestPoint:TestPoint_Pad_D1.5mm |  | F
TP6 | control | C_U0TX | Factory pogo pad | TestPoint:TestPoint_Pad_D1.5mm |  | F
TP7 | control | C_USB_N | Factory pogo pad | TestPoint:TestPoint_Pad_D1.5mm |  | F
TP8 | control | C_USB_P | Factory pogo pad | TestPoint:TestPoint_Pad_D1.5mm |  | F
SW1 | control | B3U-1000P | B3U-1000P | Button_Switch_SMD:SW_SPST_B3U-1000P | https://components.omron.com/us-en/system/files/2023-01/datasheet_pdf/A162-E1.pdf | F
R34 | control | 10k | 0603 1% 10k | Resistor_SMD:R_0603_1608Metric |  | F
C36 | control | 10n | 0603 X7R 16V 10n | Capacitor_SMD:C_0603_1608Metric |  | F
SW2 | control | B3U-1000P | B3U-1000P | Button_Switch_SMD:SW_SPST_B3U-1000P | https://components.omron.com/us-en/system/files/2023-01/datasheet_pdf/A162-E1.pdf | F
R35 | control | 10k | 0603 1% 10k | Resistor_SMD:R_0603_1608Metric |  | F
C37 | control | 10n | 0603 X7R 16V 10n | Capacitor_SMD:C_0603_1608Metric |  | F
SW3 | control | B3U-1000P | B3U-1000P | Button_Switch_SMD:SW_SPST_B3U-1000P | https://components.omron.com/us-en/system/files/2023-01/datasheet_pdf/A162-E1.pdf | F
R36 | control | 10k | 0603 1% 10k | Resistor_SMD:R_0603_1608Metric |  | F
C38 | control | 10n | 0603 X7R 16V 10n | Capacitor_SMD:C_0603_1608Metric |  | F

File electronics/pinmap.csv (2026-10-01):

Ref | Board | Pin | Pin name | Net | Domain
J1 | power | 1 | L | L_IN | live
J1 | power | 2 | N | N_IN | live
J1 | power | 3 | L1 | L_OUT1 | live
J1 | power | 4 | L2 | L_OUT2 | live
J1 | power | 5 | L3 | L_OUT3 | live
F1 | power | 1 | ~ | L_IN | live
F1 | power | 2 | ~ | H_GND | live
PS1 | power | 1 | AC_N | N_IN | live
PS1 | power | 5 | AC_L | H_GND | live
PS1 | power | 7 | 5V | C_5V | cold
PS1 | power | 9 | GND_COLD | C_GND | cold
RV1 | power | 1 | LINE | N_IN | live
RV1 | power | 2 | NEUTRAL | H_GND | live
K1 | power | 5 | ~ | C_5V | cold
K1 | power | 1 | ~ | C_COIL1 | cold
K1 | power | 3 | ~ | L_OUT1 | live
K1 | power | 2 | ~ | H_LOAD | live
Q1 | power | 1 | G | C_GATE1 | cold
Q1 | power | 2 | S | C_GND | cold
Q1 | power | 3 | D | C_COIL1 | cold
R1 | power | 1 | ~ | C_RELAY1 | cold
R1 | power | 2 | ~ | C_GATE1 | cold
R4 | power | 1 | ~ | C_GATE1 | cold
R4 | power | 2 | ~ | C_GND | cold
D1 | power | 1 | K | C_5V | cold
D1 | power | 2 | A | C_COIL1 | cold
K2 | power | 5 | ~ | C_5V | cold
K2 | power | 1 | ~ | C_COIL2 | cold
K2 | power | 3 | ~ | L_OUT2 | live
K2 | power | 2 | ~ | H_LOAD | live
Q2 | power | 1 | G | C_GATE2 | cold
Q2 | power | 2 | S | C_GND | cold
Q2 | power | 3 | D | C_COIL2 | cold
R2 | power | 1 | ~ | C_RELAY2 | cold
R2 | power | 2 | ~ | C_GATE2 | cold
R5 | power | 1 | ~ | C_GATE2 | cold
R5 | power | 2 | ~ | C_GND | cold
D2 | power | 1 | K | C_5V | cold
D2 | power | 2 | A | C_COIL2 | cold
K3 | power | 5 | ~ | C_5V | cold
K3 | power | 1 | ~ | C_COIL3 | cold
K3 | power | 3 | ~ | L_OUT3 | live
K3 | power | 2 | ~ | H_LOAD | live
Q3 | power | 1 | G | C_GATE3 | cold
Q3 | power | 2 | S | C_GND | cold
Q3 | power | 3 | D | C_COIL3 | cold
R3 | power | 1 | ~ | C_RELAY3 | cold
R3 | power | 2 | ~ | C_GATE3 | cold
R6 | power | 1 | ~ | C_GATE3 | cold
R6 | power | 2 | ~ | C_GND | cold
D3 | power | 1 | K | C_5V | cold
D3 | power | 2 | A | C_COIL3 | cold
U2 | power | 1 | EVENT1 | NC | unused
U2 | power | 2 | NC | NC | unused
U2 | power | 3 | NC | NC | unused
U2 | power | 4 | RX | H_RX | live
U2 | power | 5 | COMMONA | H_COMMON | live
U2 | power | 6 | OSCI | NC | unused
U2 | power | 7 | OSCO | NC | unused
U2 | power | 8 | NC | NC | unused
U2 | power | 9 | NC | NC | unused
U2 | power | 10 | RESET_N | H_RESET | live
U2 | power | 11 | AVDD | H_AVDD | live
U2 | power | 12 | TX | H_TX | live
U2 | power | 13 | COMMONB | H_COMMON | live
U2 | power | 14 | PWM | NC | unused
U2 | power | 15 | EVENT2 | NC | unused
U2 | power | 16 | I+ | H_IP | live
U2 | power | 17 | I- | H_IM | live
U2 | power | 18 | V- | H_VM | live
U2 | power | 19 | V+ | H_VP | live
U2 | power | 20 | AN_IN | H_GND | live
U2 | power | 21 | AGND | H_GND | live
U2 | power | 22 | ZCD | NC | unused
U2 | power | 23 | REF | H_REF | live
U2 | power | 24 | DGND | H_GND | live
U2 | power | 25 | DVDD | H_3V3 | live
U2 | power | 26 | MCLR_N | H_MCLR | live
U2 | power | 27 | DGND | H_GND | live
U2 | power | 28 | DR | NC | unused
U2 | power | 29 | EP | H_GND | live
U3 | power | 1 | VCC | C_3V3 | cold
U3 | power | 2 | GND1 | C_GND | cold
U3 | power | 3 | INA | C_UART_TX | cold
U3 | power | 4 | OUTB | C_UART_RX | cold
U3 | power | 5 | NC | NC | unused
U3 | power | 6 | NC | NC | unused
U3 | power | 7 | EN1 | C_3V3 | cold
U3 | power | 8 | GND1 | C_GND | cold
U3 | power | 9 | GND2 | H_GND | live
U3 | power | 10 | NC | NC | unused
U3 | power | 11 | SEL | H_GND | live
U3 | power | 12 | NC | NC | unused
U3 | power | 13 | INB | H_TX | live
U3 | power | 14 | OUTA | H_RX | live
U3 | power | 15 | GND2 | H_GND | live
U3 | power | 16 | VISO | H_3V3 | live
R7 | power | 1 | I_IN | H_GND | live
R7 | power | 2 | S_IN | H_KELVIN_IN | live
R7 | power | 3 | S_OUT | H_KELVIN_OUT | live
R7 | power | 4 | I_OUT | H_LOAD | live
R8 | power | 1 | ~ | H_KELVIN_OUT | live
R8 | power | 2 | ~ | H_IP | live
R9 | power | 1 | ~ | H_KELVIN_IN | live
R9 | power | 2 | ~ | H_IM | live
R10 | power | 1 | ~ | H_GND | live
R10 | power | 2 | ~ | H_VM | live
R11 | power | 1 | ~ | N_IN | live
R11 | power | 2 | ~ | H_DIV1 | live
R12 | power | 1 | ~ | H_DIV1 | live
R12 | power | 2 | ~ | H_DIV2 | live
R13 | power | 1 | ~ | H_DIV2 | live
R13 | power | 2 | ~ | H_DIV3 | live
R14 | power | 1 | ~ | H_DIV3 | live
R14 | power | 2 | ~ | H_VP | live
R15 | power | 1 | ~ | H_VP | live
R15 | power | 2 | ~ | H_GND | live
R16 | power | 1 | ~ | H_3V3 | live
R16 | power | 2 | ~ | H_AVDD | live
R17 | power | 1 | ~ | H_3V3 | live
R17 | power | 2 | ~ | H_RESET | live
R18 | power | 1 | ~ | H_3V3 | live
R18 | power | 2 | ~ | H_MCLR | live
C1 | power | 1 | ~ | H_IP | live
C1 | power | 2 | ~ | H_GND | live
C2 | power | 1 | ~ | H_IM | live
C2 | power | 2 | ~ | H_GND | live
C3 | power | 1 | ~ | H_VM | live
C3 | power | 2 | ~ | H_GND | live
C4 | power | 1 | ~ | H_VP | live
C4 | power | 2 | ~ | H_GND | live
C5 | power | 1 | ~ | H_AVDD | live
C5 | power | 2 | ~ | H_GND | live
C6 | power | 1 | ~ | H_AVDD | live
C6 | power | 2 | ~ | H_GND | live
C7 | power | 1 | ~ | H_3V3 | live
C7 | power | 2 | ~ | H_GND | live
C8 | power | 1 | ~ | H_REF | live
C8 | power | 2 | ~ | H_GND | live
C9 | power | 1 | ~ | H_RESET | live
C9 | power | 2 | ~ | H_GND | live
C10 | power | 1 | ~ | H_MCLR | live
C10 | power | 2 | ~ | H_GND | live
C11 | power | 1 | ~ | H_3V3 | live
C11 | power | 2 | ~ | H_GND | live
C12 | power | 1 | ~ | H_3V3 | live
C12 | power | 2 | ~ | H_GND | live
C13 | power | 1 | ~ | C_3V3 | cold
C13 | power | 2 | ~ | C_GND | cold
C14 | power | 1 | ~ | C_3V3 | cold
C14 | power | 2 | ~ | C_GND | cold
C15 | power | 1 | ~ | C_3V3 | cold
C15 | power | 2 | ~ | C_GND | cold
C16 | power | 1 | ~ | C_5V | cold
C16 | power | 2 | ~ | C_GND | cold
J2 | power | 1 | 5V | C_5V | cold
J2 | power | 2 | GND | C_GND | cold
J2 | power | 3 | 3V3 | C_3V3 | cold
J2 | power | 4 | RLY1 | C_RELAY1 | cold
J2 | power | 5 | RLY2 | C_RELAY2 | cold
J2 | power | 6 | RLY3 | C_RELAY3 | cold
J2 | power | 7 | TX | C_UART_TX | cold
J2 | power | 8 | RX | C_UART_RX | cold
J3 | control | 1 | 5V | C_5V | cold
J3 | control | 2 | GND | C_GND | cold
J3 | control | 3 | 3V3 | C_3V3 | cold
J3 | control | 4 | RLY1 | C_RELAY1 | cold
J3 | control | 5 | RLY2 | C_RELAY2 | cold
J3 | control | 6 | RLY3 | C_RELAY3 | cold
J3 | control | 7 | TX | C_UART_TX | cold
J3 | control | 8 | RX | C_UART_RX | cold
U1 | control | 1 | GND | C_GND | cold
U1 | control | 2 | GND | C_GND | cold
U1 | control | 3 | 3V3 | C_3V3 | cold
U1 | control | 4 | NC | NC | unused
U1 | control | 5 | IO2 | C_STRAP2 | cold
U1 | control | 6 | IO3 | C_RELAY3 | cold
U1 | control | 7 | NC | NC | unused
U1 | control | 8 | EN | C_EN | cold
U1 | control | 9 | NC | NC | unused
U1 | control | 10 | NC | NC | unused
U1 | control | 11 | GND | C_GND | cold
U1 | control | 12 | IO0 | C_RELAY1 | cold
U1 | control | 13 | IO1 | C_RELAY2 | cold
U1 | control | 14 | GND | C_GND | cold
U1 | control | 15 | NC | NC | unused
U1 | control | 16 | IO10 | C_UART_TX | cold
U1 | control | 17 | NC | NC | unused
U1 | control | 18 | IO4 | C_KEY1 | cold
U1 | control | 19 | IO5 | C_KEY2 | cold
U1 | control | 20 | IO6 | C_KEY3 | cold
U1 | control | 21 | IO7 | C_UART_RX | cold
U1 | control | 22 | IO8 | C_STRAP8 | cold
U1 | control | 23 | IO9 | C_BOOT | cold
U1 | control | 24 | NC | NC | unused
U1 | control | 25 | NC | NC | unused
U1 | control | 26 | IO18 | C_USB_N | cold
U1 | control | 27 | IO19 | C_USB_P | cold
U1 | control | 28 | NC | NC | unused
U1 | control | 29 | NC | NC | unused
U1 | control | 30 | IO20 | C_U0RX | cold
U1 | control | 31 | IO21 | C_U0TX | cold
U1 | control | 32 | NC | NC | unused
U1 | control | 33 | NC | NC | unused
U1 | control | 34 | NC | NC | unused
U1 | control | 35 | NC | NC | unused
U1 | control | 36 | GND | C_GND | cold
U1 | control | 37 | GND | C_GND | cold
U1 | control | 38 | GND | C_GND | cold
U1 | control | 39 | GND | C_GND | cold
U1 | control | 40 | GND | C_GND | cold
U1 | control | 41 | GND | C_GND | cold
U1 | control | 42 | GND | C_GND | cold
U1 | control | 43 | GND | C_GND | cold
U1 | control | 44 | GND | C_GND | cold
U1 | control | 45 | GND | C_GND | cold
U1 | control | 46 | GND | C_GND | cold
U1 | control | 47 | GND | C_GND | cold
U1 | control | 48 | GND | C_GND | cold
U1 | control | 49 | GND | C_GND | cold
U1 | control | 50 | GND | C_GND | cold
U1 | control | 51 | GND | C_GND | cold
U1 | control | 52 | GND | C_GND | cold
U1 | control | 53 | GND | C_GND | cold
R30 | control | 1 | ~ | C_3V3 | cold
R30 | control | 2 | ~ | C_EN | cold
R31 | control | 1 | ~ | C_3V3 | cold
R31 | control | 2 | ~ | C_STRAP2 | cold
R32 | control | 1 | ~ | C_3V3 | cold
R32 | control | 2 | ~ | C_STRAP8 | cold
R33 | control | 1 | ~ | C_3V3 | cold
R33 | control | 2 | ~ | C_BOOT | cold
C30 | control | 1 | ~ | C_EN | cold
C30 | control | 2 | ~ | C_GND | cold
C31 | control | 1 | ~ | C_3V3 | cold
C31 | control | 2 | ~ | C_GND | cold
C32 | control | 1 | ~ | C_3V3 | cold
C32 | control | 2 | ~ | C_GND | cold
U4 | control | 1 | GND | C_GND | cold
U4 | control | 2 | OUT/TAB | C_3V3 | cold
U4 | control | 3 | IN | C_5V | cold
C33 | control | 1 | ~ | C_5V | cold
C33 | control | 2 | ~ | C_GND | cold
C34 | control | 1 | ~ | C_3V3 | cold
C34 | control | 2 | ~ | C_GND | cold
C35 | control | 1 | ~ | C_3V3 | cold
C35 | control | 2 | ~ | C_GND | cold
TP1 | control | 1 | 1 | C_GND | cold
TP2 | control | 1 | 1 | C_3V3 | cold
TP3 | control | 1 | 1 | C_EN | cold
TP4 | control | 1 | 1 | C_BOOT | cold
TP5 | control | 1 | 1 | C_U0RX | cold
TP6 | control | 1 | 1 | C_U0TX | cold
TP7 | control | 1 | 1 | C_USB_N | cold
TP8 | control | 1 | 1 | C_USB_P | cold
SW1 | control | 1 | 1 | C_KEY1 | cold
SW1 | control | 2 | 2 | C_GND | cold
R34 | control | 1 | ~ | C_3V3 | cold
R34 | control | 2 | ~ | C_KEY1 | cold
C36 | control | 1 | ~ | C_KEY1 | cold
C36 | control | 2 | ~ | C_GND | cold
SW2 | control | 1 | 1 | C_KEY2 | cold
SW2 | control | 2 | 2 | C_GND | cold
R35 | control | 1 | ~ | C_3V3 | cold
R35 | control | 2 | ~ | C_KEY2 | cold
C37 | control | 1 | ~ | C_KEY2 | cold
C37 | control | 2 | ~ | C_GND | cold
SW3 | control | 1 | 1 | C_KEY3 | cold
SW3 | control | 2 | 2 | C_GND | cold
R36 | control | 1 | ~ | C_3V3 | cold
R36 | control | 2 | ~ | C_KEY3 | cold
C38 | control | 1 | ~ | C_KEY3 | cold
C38 | control | 2 | ~ | C_GND | cold

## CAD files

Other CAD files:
mechanical/carbentra_smart_switch.blend
mechanical/carbentra_smart_switch_animation.blend

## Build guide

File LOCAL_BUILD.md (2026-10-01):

# Windows local build

The supported local workflow is PowerShell 7, uv-managed Python 3.12, MSVC 2022, KiCad 10.0.5 (including its own pcbnew Python), Blender 5.2.2 LTS, Inkscape 1.4.4, FFmpeg, CMake and Ninja. Blender and KiCad retain their own embedded interpreters; they are not installed into the general Python environment.

```powershell
uv venv --python 3.12
uv sync --frozen
$env:KICAD_BIN = 'D:\Dev\KiCad\10.0\bin'
$env:BLENDER_EXE = 'C:\Program Files\Blender Foundation\Blender 5.2\blender.exe'
$env:INKSCAPE_BIN = 'D:\Dev\Inkscape-1.4.4\inkscape\bin'
$build = 'D:\Temp\codex\carbentra-local-build'
```

Paths above are examples of the verified workstation. Set each variable to your own installed tool. CMake, Ninja and FFmpeg must be callable; `INKSCAPE_BIN` is added to PATH by the coordinator. The project never installs CAD Python packages into its venv. `dev.ps1` loads the installed MSVC developer shell for host checks.

## ESP32-C3 target

Install official [ESP-IDF 5.4.3](https://github.com/espressif/esp-idf/tree/v5.4.3), including recursive submodules, at the exact commit in `firmware/dependencies.lock.json`. Use official `tools/idf_tools.py install --targets esp32c3` for matching Windows tools. The SDK needs a separate Python 3.12 environment: create it with `uv venv <IDF_PYTHON_ENV_PATH>` **before** installing the SDK's official `requirements.core.txt` under its official v5.4 constraints. Preserve SDK metadata and check `idf_tools.py check-python-dependencies`. Do not put SDK packages into the project's CAD/report venv.

```powershell
$env:IDF_PATH = 'D:\Dev\esp-idf-v5.4.3'
$env:IDF_TOOLS_PATH = 'D:\Dev\esp-tools-v5.4.3'
$env:IDF_PYTHON_ENV_PATH = 'D:\Dev\esp-tools-v5.4.3\python_env\idf5.4_py3.12_env'
```

The coordinator uses the SDK's official tool-path export and builds an external copy of `sdkconfig`. It refuses an unpinned SDK. The resulting image has `CONFIG_CARBENTRA_SWITCH_ALLOW_ACTUATION` disabled; no credentials or commissioning records are generated.

## Run

```powershell
.\scripts\dev.ps1 -Action all -BuildRoot $build
.\scripts\dev.ps1 -Action render -BuildRoot $build
```

`all` runs native C host tests, a real MCU target build, strict ERC/DRC and native schematic/PCB connectivity checks, manufacturing exports, parametric mechanical rebuild, exported-file reopening and geometric checks. `render` separately regenerates geometry and presentation media, with OptiX then CUDA preferred when supported and CPU fallback. Run GPU render jobs sequentially on an 8 GB device.

Each invocation prints `VALIDATED_OUTPUT` and creates an independent timestamped directory with `validation.json`. Outputs, temporary files and child-process TEMP/TMP stay under the explicit external build root. The source checkout is not overwritten. To run one stage, use `host`, `target`, `electronics` or `mechanical`.

Native KiCad files are the circuit source of truth. The reproducible boundary is **native circuit → strict checks → fabrication/presentation exports**, not re-running an old autorouter to recover identical routing. One-time ECO and placement/autorouting tools were retired into Git history. Blender parameter scripts recreate the engineering model; saved `.blend` files remain editable reference sources. Geometric checks do not establish production tolerances.

The current Windows host run uses MSVC strict warnings and CTest; it does not claim UBSan or LeakSanitizer coverage. Source history contains earlier Linux sanitizer runs, which are not substituted for current evidence. Nothing here flashes hardware, provisions keys or actuates a load. Compact current evidence is in `verification/local-validation.json`; binary/media bundles belong in GitHub Releases. Delete your external build directory after preserving results you need.

## Host CI without CAD or target SDKs

The Windows GitHub Actions workflow pins uv 0.11.17 and Python 3.12, creates the venv before dependency installation, and runs the same PowerShell host entry. It installs no KiCad, Blender, Zephyr or ESP-IDF toolchain. Local verification of this path passed; a GitHub run is a separate result.

For Switch, set CJSON_ROOT to a standalone checkout at the exact sdk_submodules.cJSON commit in firmware/dependencies.lock.json. The coordinator verifies the commit before compiling. If that variable is absent, the existing IDF_PATH/components/json/cJSON source is used. CI fetches only this small upstream dependency and does not alter the pin.

CTest additionally runs `firmware/tests/check_tls_config.py`, which checks both
maintained TLS date configurations and compiles the actual `tls_policy.h` against
positive/negative host fixtures. The target coordinator checks its generated
sdkconfig after building; the real network translation unit includes the guard.

The independent certificate behavior test is a separate host-library gate. With
a development mbedTLS installation and Python `cryptography`, compile
`firmware/tests/test_certificate_policy.c` against that installation's `mbedx509`
and `mbedcrypto` libraries, then run:

```sh
python firmware/tests/check_certificate_policy.py --verifier /external-build/switch_certificate_policy
```

The binary argument is mandatory and missing binaries are errors, not skips.
This checks valid/expired/future/wrong-CA/wrong-hostname certificates using that
host library. Record its version. It does not replace a pinned ESP-IDF target
build or MQTT handshake tests on the ESP32-C3.

On Windows and POSIX hosts, target builds additionally run `firmware/tools/check_target_tls_guard.py`
against the generated compilation database. It recompiles the actual `network.c`
with its real ESP32-C3 compiler/SDK headers, checks the successful generated config,
and requires compilation to fail when time/date checks are disabled or insecure
TLS is enabled in a temporary header overlay. It writes only external temporary
objects and `target-tls-guard.json`; it never links or flashes an unsafe image.
This is target **compile** evidence, not certificate-handshake execution evidence.

## Source byte identity

The checked-in .gitattributes keeps native KiCad/JSON bytes unchanged and checks ordinary code out with LF on every platform. verification/source-manifest.json hashes the published source bytes; those hashes are checked against Git blobs, not only one Windows working tree. The complete build was rerun after text normalization. Earlier render-execution hashes are explicitly historical working-tree hashes; CAD bytes and geometric inputs did not change, so media was not rerendered solely for newline conversion.

Current source byte inventory is checked with `python scripts/source_manifest.py`.
After intentional source changes and completed relevant tests, refresh it using
`python scripts/source_manifest.py --write`. This records exact checkout bytes; it
does not rerun or renew the historical Windows/CAD/media qualification reports.
The current firmware-only evidence is `firmware/remediation-report.json`.

## Firmware release without rerunning CAD

With the SDK environment above, run the real host suite and MCU build together:

```powershell
.\scripts\dev.ps1 -Action firmware -BuildRoot $build
```

The printed run directory contains `validation.json`, binding firmware/build
inputs captured before and after the run, compiled target/configuration bytes,
and safety checks. Switch also runs actual target TLS compile-negative controls
on Windows. This action does not run CAD, rendering or physical verification.

Set `$run` to that printed directory and `$release` to an external output directory:

```powershell
.\.venv\Scripts\python.exe scripts/package_release.py --build-output $run --destination $release
```

Optionally add `--historical-assets $earlierZip` and
`--historical-assets-sha256 $publishedSha256` to retain earlier CAD/media. The
archive and every member are hash-checked, and its CAD/media input inventory must
match the current checkout. Its old firmware is excluded. Historical reports go
under `verification/historical-assets`; the current target report is
`verification/firmware-build-run.json`. Missing source/artifact binding, altered
target/configuration, missing safety proof or stale firmware inputs block output.
Earlier remediation reports are historical and cannot substitute for this run.

The regression uses real current and earlier target bytes in external copies:

```powershell
.\.venv\Scripts\python.exe scripts/tests/check_release.py --build-output $run --historical-assets $earlierZip --historical-assets-sha256 $publishedSha256 --output $externalTestDirectory
```

After intentional source/report edits, refresh `scripts/source_manifest.py --write`
before packaging. This is an inventory operation, never a substitute for a build.
Latest executed firmware and packaging proof:
`verification/current-firmware-validation.json`. Earlier Linux and Windows/CAD
reports retain their original execution hashes and qualification limits.

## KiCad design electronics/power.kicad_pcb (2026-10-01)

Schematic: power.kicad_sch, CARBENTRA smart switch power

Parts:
C1, C2, C3, C4: 33n; C_0603_1608Metric
C5: 1u; C_0603_1608Metric
C6, C7, C8, C9, C10, C12, C14: 100n; C_0603_1608Metric
C11, C13: 10u; C_0805_2012Metric
C15: 220u 6.3V; CP_Elec_6.3x5.8
C16: 100u 10V; CP_Elec_6.3x5.8
D1, D2, D3: SS14; D_SMA
F1: T2A 277VAC / 1500A BC; UMT_H
J1: L N L1 L2 L3; TerminalBlock_Phoenix_MKDS-1,5-5-5.08_1x05_P5.08mm_Horizont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
J2: COLD LINK / JST-PH8; JST_PH_B8B-PH-K_1x08_P2.00mm_Vertical
K1, K2, K3: G5Q-1A DC5; Relay_SPST_Omron-G5Q-1A
PS1: RAC05-05SK/277; RAC05_05SK_277
Q1, Q2, Q3: AO3400A; SOT-23
R1, R2, R3: 100R; R_0603_1608Metric
R4, R5, R6: 100k; R_0603_1608Metric
R7: 2mR 4-terminal Kelvin; R_Shunt_Vishay_WSK2512_6332Metric_T2.21mm
R8, R9, R10, R15: 1k; R_0603_1608Metric
R11, R12, R13, R14: 249k; R_1206_3216Metric
R16: 10R; R_0603_1608Metric
R17, R18: 10k; R_0603_1608Metric
RV1: TMOV14RP275E; TMOV14
U2: MCP39F511A-E/MQ; QFN-28-1EP_5x5mm_P0.5mm_EP3.25x3.25mm
U3: ISOW7821DWER; ISOW7821_DWE

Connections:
C_3V3: C13.1, C14.1, C15.1, J2.3 (3V3), U3.1 (VCC), U3.7 (EN1)
C_5V: C16.1, D1.1 (K), D2.1 (K), D3.1 (K), J2.1 (5V), K1.5, K2.5, K3.5, PS1.7 (5V)
C_COIL1: D1.2 (A), K1.1, Q1.3 (D)
C_COIL2: D2.2 (A), K2.1, Q2.3 (D)
C_COIL3: D3.2 (A), K3.1, Q3.3 (D)
C_GATE1: Q1.1 (G), R1.2, R4.1
C_GATE2: Q2.1 (G), R2.2, R5.1
C_GATE3: Q3.1 (G), R3.2, R6.1
C_GND: C13.2, C14.2, C15.2, C16.2, J2.2 (GND), PS1.9 (GND_COLD), Q1.2 (S), Q2.2 (S), Q3.2 (S), R4.2, R5.2, R6.2, U3.2 (GND1), U3.8 (GND1)
C_RELAY1: J2.4 (RLY1), R1.1
C_RELAY2: J2.5 (RLY2), R2.1
C_RELAY3: J2.6 (RLY3), R3.1
C_UART_RX: J2.8 (RX), U3.4 (OUTB)
C_UART_TX: J2.7 (TX), U3.3 (INA)
H_3V3: C7.1, C11.1, C12.1, R16.1, R17.1, R18.1, U2.25 (DVDD), U3.16 (VISO)
H_AVDD: C5.1, C6.1, R16.2, U2.11 (AVDD)
H_COMMON: U2.5 (COMMONA), U2.13 (COMMONB)
H_DIV1: R11.2, R12.1
H_DIV2: R12.2, R13.1
H_DIV3: R13.2, R14.1
H_GND: C1.2, C2.2, C3.2, C4.2, C5.2, C6.2, C7.2, C8.2, C9.2, C10.2, C11.2, C12.2, F1.2, PS1.5 (AC_L), R7.1 (I_IN), R10.1, R15.2, RV1.2 (NEUTRAL), U2.20 (AN_IN), U2.21 (AGND), U2.24 (DGND), U2.27 (DGND), U2.29 (EP), U3.9 (GND2), U3.11 (SEL), U3.15 (GND2)
H_IM: C2.1, R9.2, U2.17 (I-)
H_IP: C1.1, R8.2, U2.16 (I+)
H_KELVIN_IN: R7.2 (S_IN), R9.1
H_KELVIN_OUT: R7.3 (S_OUT), R8.1
H_LOAD: K1.2, K2.2, K3.2, R7.4 (I_OUT)
H_MCLR: C10.1, R18.2, U2.26 (MCLR_N)
H_REF: C8.1, U2.23 (REF)
H_RESET: C9.1, R17.2, U2.10 (RESET_N)
H_RX: U2.4 (RX), U3.14 (OUTA)
H_TX: U2.12 (TX), U3.13 (INB)
H_VM: C3.1, R10.2, U2.18 (V-)
H_VP: C4.1, R14.2, R15.1, U2.19 (V+)
L_IN: F1.1, J1.1 (L)
L_OUT1: J1.3 (L1), K1.3
L_OUT2: J1.4 (L2), K2.3
L_OUT3: J1.5 (L3), K3.3
N_IN: J1.2 (N), PS1.1 (AC_N), R11.1, RV1.1 (LINE)

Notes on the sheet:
01 / MAINS + PROTECTION + ISOLATED PSU
02 / THREE INDEPENDENT RELAYS + DRIVERS
03 / AGGREGATE METER + REINFORCED BARRIER
CARBENTRA / SMART LIGHT SWITCH / POWER / A-CANDIDATE
DEVELOPMENT ONLY: neutral 220VAC / no dimming / no physical contact feedback / never energize this unqualified prototype
H_* is LIVE-domain. C_* is isolated control. No ground tie across barrier. ERC/DRC do not qualify mains safety.

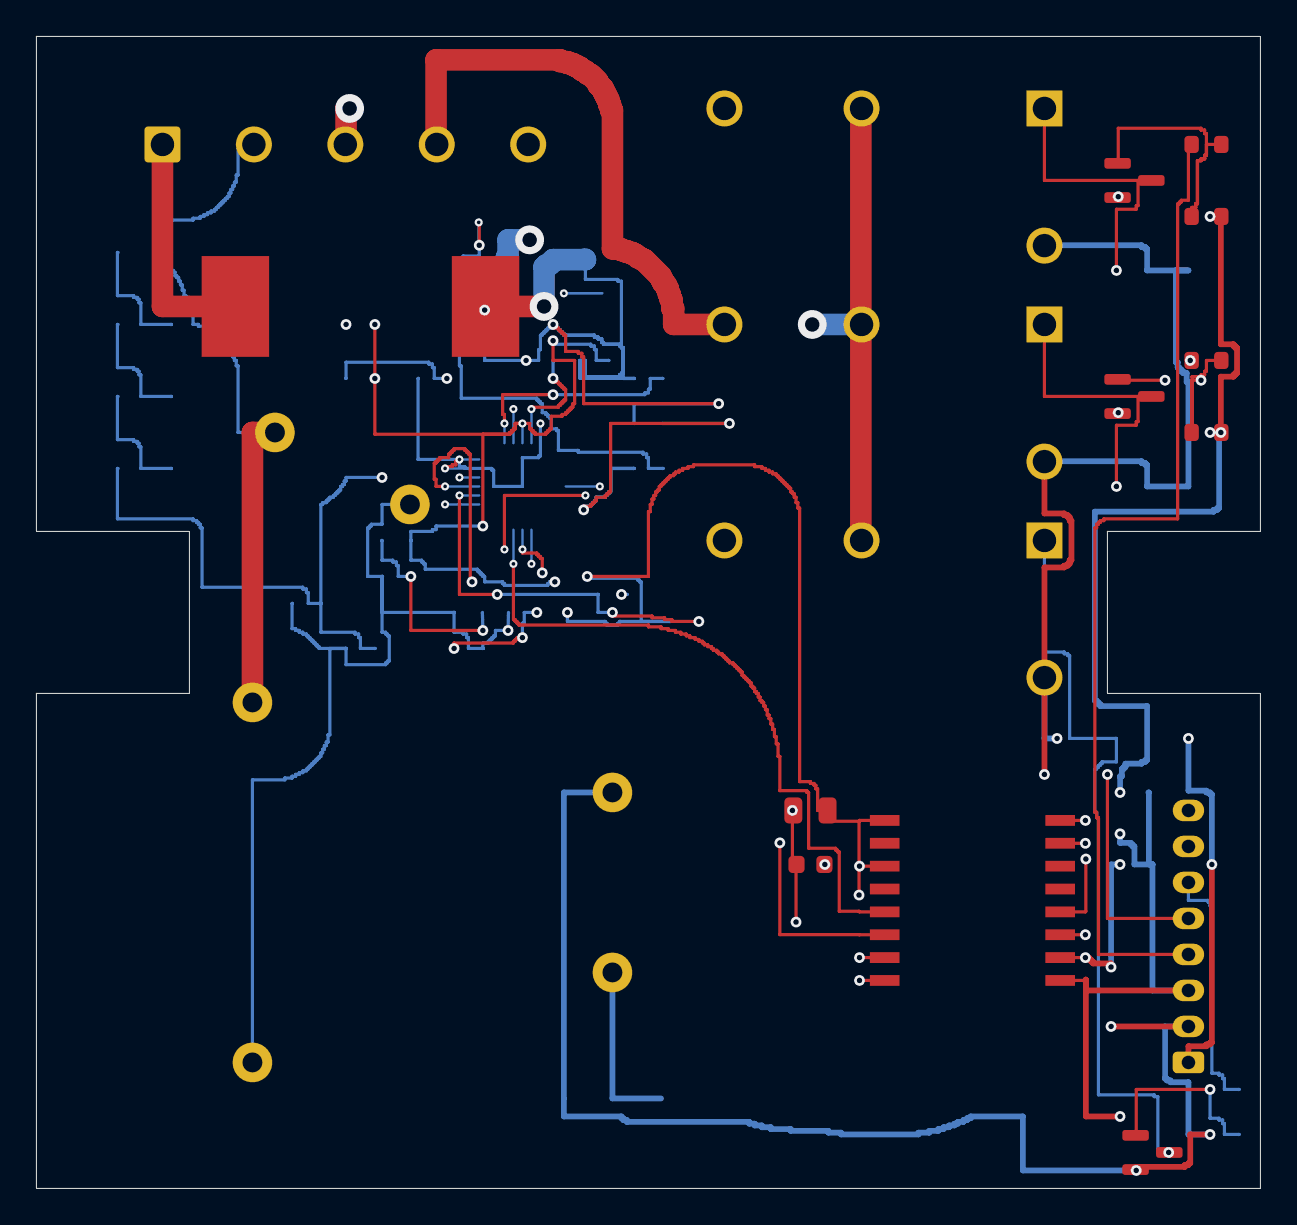
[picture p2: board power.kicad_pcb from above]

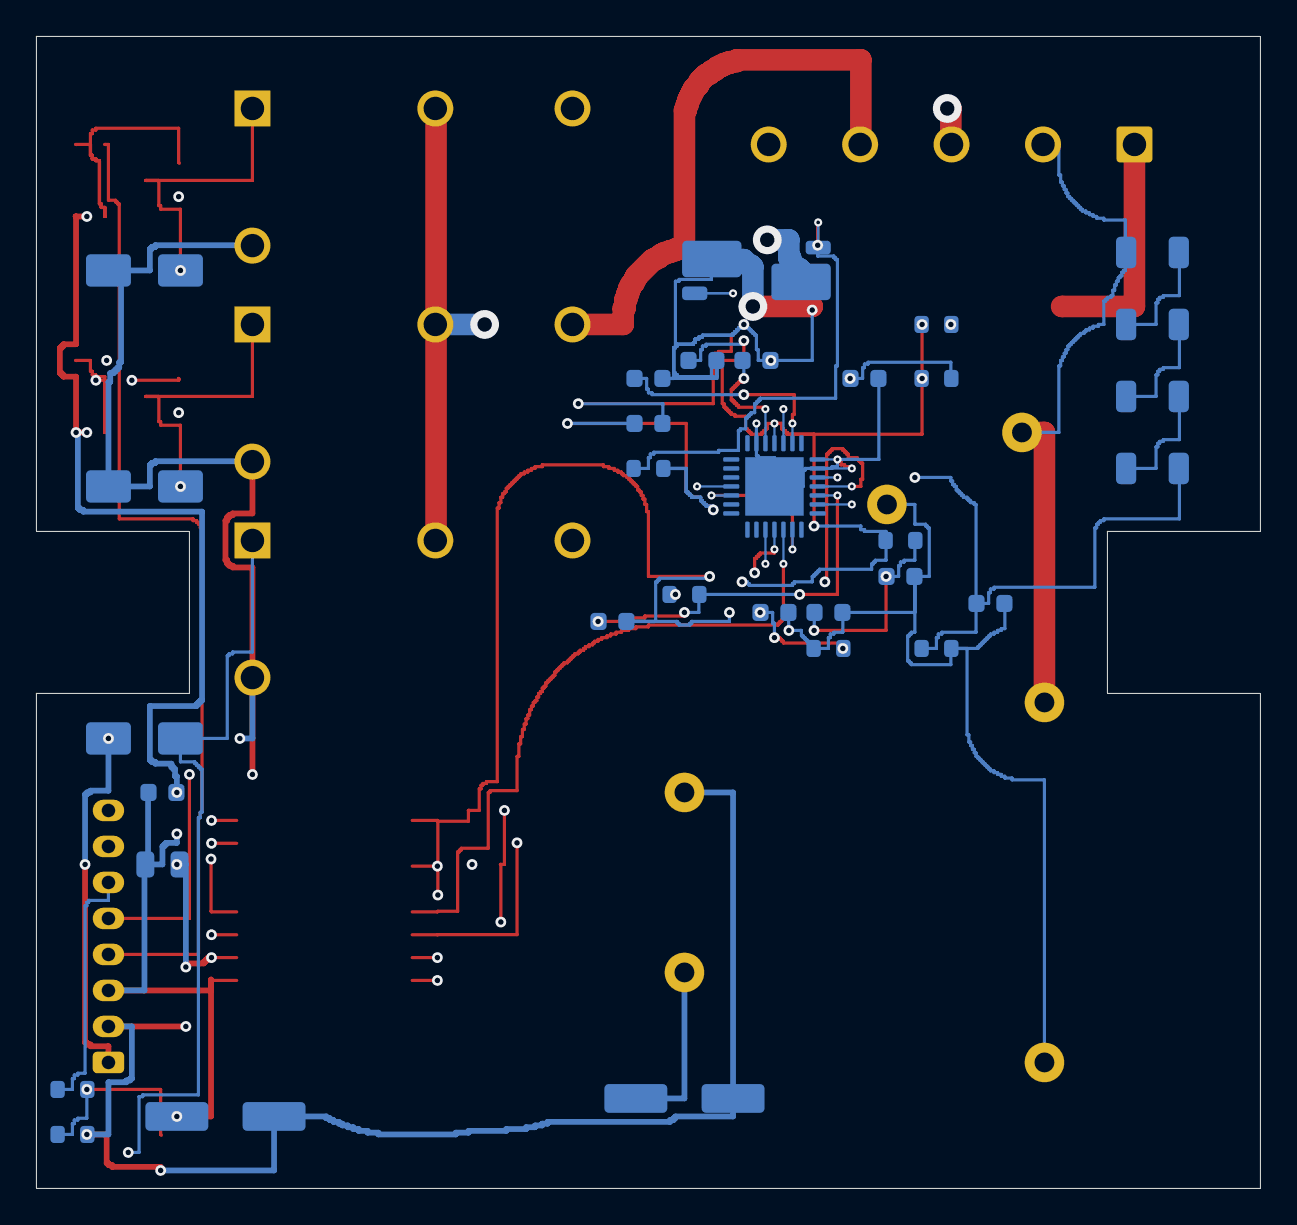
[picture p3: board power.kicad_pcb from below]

Board: 4 copper layers, 68.0 x 64.0 mm, 50 parts (32 on the bottom side), 38 nets.

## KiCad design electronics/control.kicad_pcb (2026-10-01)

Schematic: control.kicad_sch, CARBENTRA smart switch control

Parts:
C30: 1u; C_0603_1608Metric
C31: 10u; C_0805_2012Metric
C32, C35: 100n; C_0603_1608Metric
C33, C34: 22u; C_1206_3216Metric
C36, C37, C38: 10n; C_0603_1608Metric
J3: COLD LINK / JST-PH8; JST_PH_B8B-PH-K_1x08_P2.00mm_Vertical
R30, R31, R32, R33, R34, R35, R36: 10k; R_0603_1608Metric
SW1, SW2, SW3: B3U-1000P; SW_SPST_B3U-1000P
TP1: C_GND; TestPoint_Pad_D1.5mm
TP2: C_3V3; TestPoint_Pad_D1.5mm
TP3: C_EN; TestPoint_Pad_D1.5mm
TP4: C_BOOT; TestPoint_Pad_D1.5mm
TP5: C_U0RX; TestPoint_Pad_D1.5mm
TP6: C_U0TX; TestPoint_Pad_D1.5mm
TP7: C_USB_N; TestPoint_Pad_D1.5mm
TP8: C_USB_P; TestPoint_Pad_D1.5mm
U1: ESP32-C3-MINI-1-N4X; ESP32_C3_MINI_1
U4: TLV1117LV33DCYR; SOT-223-3_TabPin2

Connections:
C_3V3: C31.1, C32.1, C34.1, C35.1, J3.3 (3V3), R30.1, R31.1, R32.1, R33.1, R34.1, R35.1, R36.1, TP2.1, U1.3 (3V3), U4.2 (OUT/TAB)
C_5V: C33.1, J3.1 (5V), U4.3 (IN)
C_BOOT: R33.2, TP4.1, U1.23 (IO9)
C_EN: C30.1, R30.2, TP3.1, U1.8 (EN)
C_GND: C30.2, C31.2, C32.2, C33.2, C34.2, C35.2, C36.2, C37.2, C38.2, J3.2 (GND), SW1.2, SW2.2, SW3.2, TP1.1, U1.1 (GND), U1.2 (GND), U1.11 (GND), U1.14 (GND), U1.36 (GND), U1.37 (GND), U1.38 (GND), U1.39 (GND), U1.40 (GND), U1.41 (GND), U1.42 (GND), U1.43 (GND), U1.44 (GND), U1.45 (GND), U1.46 (GND), U1.47 (GND), U1.48 (GND), U1.49 (GND), U1.50 (GND), U1.51 (GND), U1.52 (GND), U1.53 (GND), U4.1 (GND)
C_KEY1: C36.1, R34.2, SW1.1, U1.18 (IO4)
C_KEY2: C37.1, R35.2, SW2.1, U1.19 (IO5)
C_KEY3: C38.1, R36.2, SW3.1, U1.20 (IO6)
C_RELAY1: J3.4 (RLY1), U1.12 (IO0)
C_RELAY2: J3.5 (RLY2), U1.13 (IO1)
C_RELAY3: J3.6 (RLY3), U1.6 (IO3)
C_STRAP2: R31.2, U1.5 (IO2)
C_STRAP8: R32.2, U1.22 (IO8)
C_U0RX: TP5.1, U1.30 (IO20)
C_U0TX: TP6.1, U1.31 (IO21)
C_UART_RX: J3.8 (RX), U1.21 (IO7)
C_UART_TX: J3.7 (TX), U1.16 (IO10)
C_USB_N: TP7.1, U1.26 (IO18)
C_USB_P: TP8.1, U1.27 (IO19)

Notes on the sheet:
04 / WI-FI + BLE RADIO + BOOT SUPPORT
05 / COLD 3.3V POWER + SERVICE + LINK
06 / THREE OFFLINE LOCAL BUTTONS
CARBENTRA / SMART LIGHT SWITCH / CONTROL / A-CANDIDATE
DEVELOPMENT ONLY: neutral 220VAC / no dimming / no physical contact feedback / never energize this unqualified prototype
H_* is LIVE-domain. C_* is isolated control. No ground tie across barrier. ERC/DRC do not qualify mains safety.

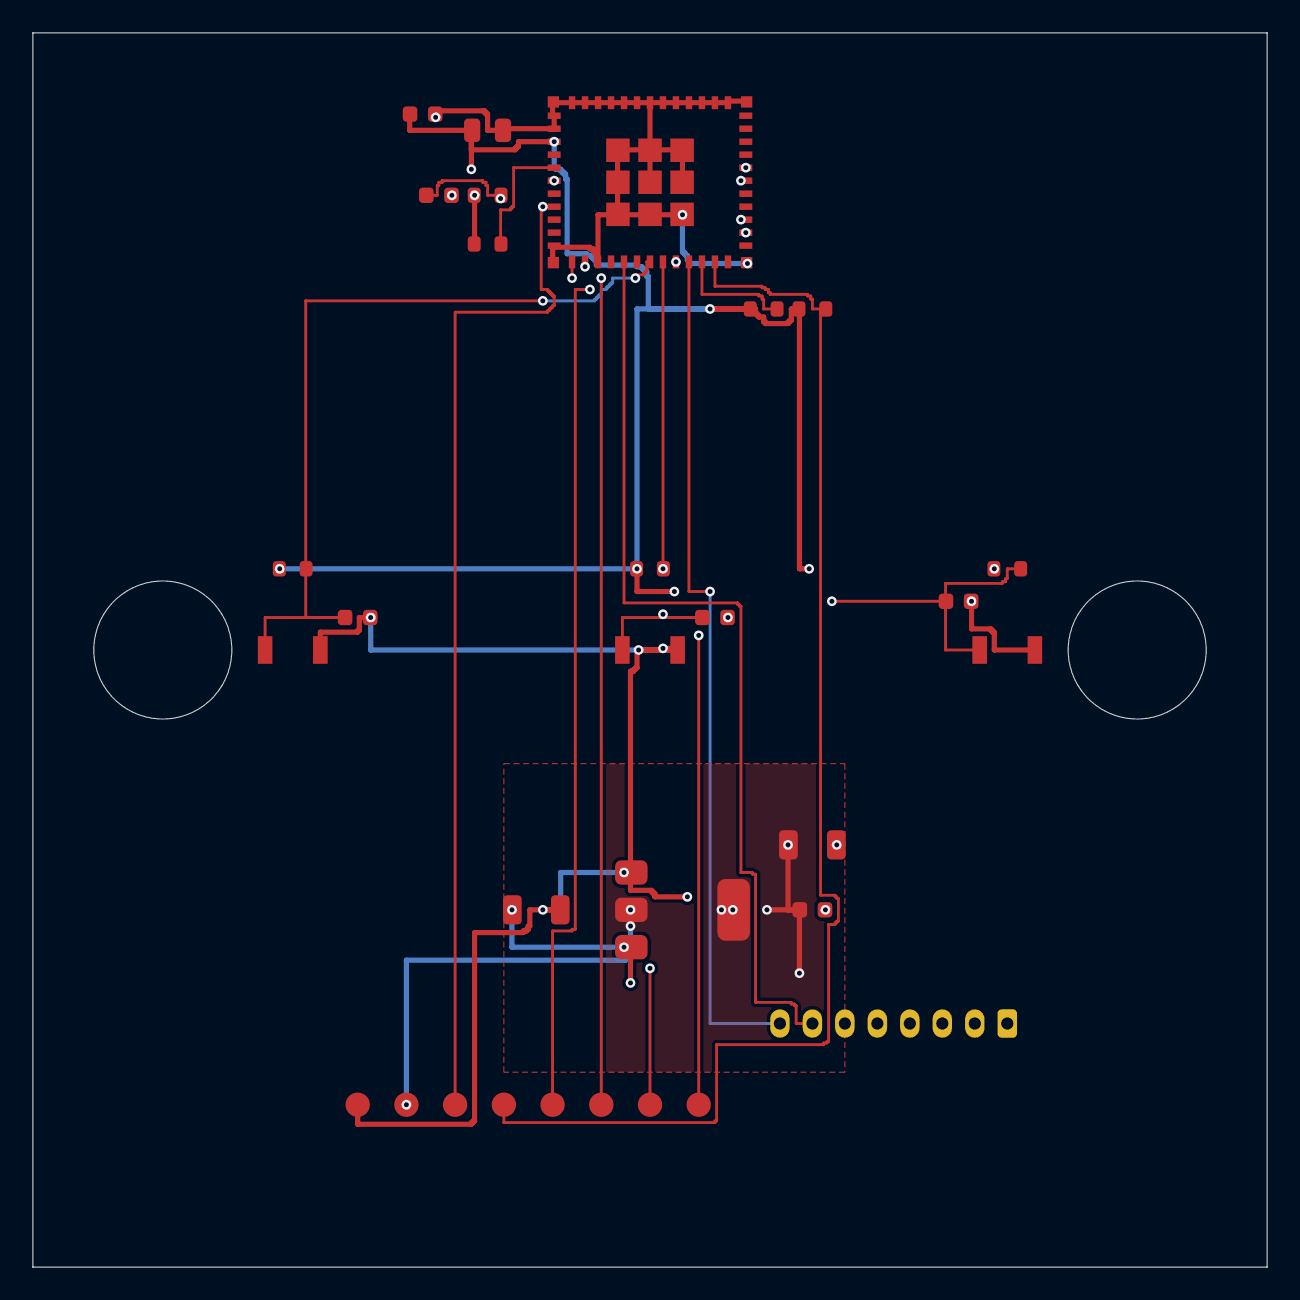
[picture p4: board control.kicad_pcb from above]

Board: 4 copper layers, 76.0 x 76.0 mm, 32 parts (1 on the bottom side), 19 nets.

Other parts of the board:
H1, H2: MountHole8_5

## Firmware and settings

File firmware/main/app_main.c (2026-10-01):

#include <inttypes.h>
#include <stdio.h>
#include "bootloader_random.h"
#include <string.h>
#include "freertos/FreeRTOS.h"
#include "freertos/task.h"
#include "freertos/semphr.h"
#include "driver/gpio.h"
#include "driver/uart.h"
#include "esp_log.h"
#include "esp_random.h"
#include "esp_timer.h"
#include "nvs_flash.h"
#include "nvs.h"
#include "board.h"
#include "app_state.h"
#include "device_config.h"
#include "network.h"
static const char *TAG="switch";
static const int relays[]={RELAY1_GPIO,RELAY2_GPIO,RELAY3_GPIO};
static const int keys[]={KEY1_GPIO,KEY2_GPIO,KEY3_GPIO};
static app_snapshot_t state;
static SemaphoreHandle_t state_lock;
static device_config_t config;
static uint64_t now_ms(void){return (uint64_t)esp_timer_get_time()/1000;}
static void drive_outputs(void){
    for(unsigned i=0;i<3;i++){
#if CONFIG_CARBENTRA_SWITCH_ALLOW_ACTUATION
        bool on=state.control.commissioned&&!state.control.fault_latched&&!state.control.maintenance&&state.control.commanded[i];
#else
        bool on=false;
#endif
        if(gpio_set_level(relays[i],on?1:0)!=ESP_OK){
            switch_latch_fault(&state.control);
            for(unsigned j=0;j<3;j++)gpio_set_level(relays[j],0);
            break;
        }
    }
}
void app_snapshot(app_snapshot_t *out){xSemaphoreTake(state_lock,portMAX_DELAY);*out=state;out->uptime_ms=now_ms();xSemaphoreGive(state_lock);}
switch_result_t app_command(const switch_command_t *command){
    xSemaphoreTake(state_lock,portMAX_DELAY);
    switch_result_t result=switch_apply(&state.control,command,now_ms());
    if(result==SWITCH_APPLIED){drive_outputs();if(state.control.fault_latched)result=SWITCH_FAULT;}
    xSemaphoreGive(state_lock);return result;
}
static void key_task(void *unused){
    (void)unused;
    for(;;){
        xSemaphoreTake(state_lock,portMAX_DELAY);
        bool changed=false;uint64_t now=now_ms();
        for(unsigned i=0;i<3;i++)changed|=switch_key_sample(&state.control,i,gpio_get_level(keys[i])==0,now);
        if(changed)drive_outputs();
        xSemaphoreGive(state_lock);vTaskDelay(pdMS_TO_TICKS(10));
    }
}
static bool read_registers(uint16_t address,uint8_t *data,uint8_t count){
    uint8_t request[8],frame[35];size_t have=0,total=(size_t)count+3;
    if(!mcp_read_request(address,count,request))return false;
    uart_flush_input(METER_UART);
    if(uart_write_bytes(METER_UART,request,sizeof(request))!=(int)sizeof(request))return false;
    uint64_t deadline=now_ms()+250;
    while(have<total && now_ms()<deadline){
        int n=uart_read_bytes(METER_UART,frame+have,total-have,pdMS_TO_TICKS(20));
        if(n>0)have+=(size_t)n;
        if(have && frame[0]!=0x06)return false;
    }
    return mcp_read_response(frame,have,count,data);
}
static bool profile_matches(void){
    if(!config.calibration_ready)return false;
    /* Unframed 0x5A is the documented model probe, not the framed calibration command. */
    const uint8_t probe=0x5A;uint8_t identity[2];uart_flush_input(METER_UART);
    if(uart_write_bytes(METER_UART,&probe,1)!=1 || uart_read_bytes(METER_UART,identity,2,pdMS_TO_TICKS(200))!=2 || identity[0]!=0x15 || identity[1]!=0x04)return false;
    uint8_t bytes[32];
    for(size_t offset=0;offset<MCP_PROFILE_SIZE;offset+=32){
        size_t n=MCP_PROFILE_SIZE-offset;if(n>32)n=32;
        if(!read_registers(MCP_PROFILE_START+offset,bytes,(uint8_t)n)||memcmp(bytes,config.meter_profile+offset,n))return false;
    }
    return true;
}
static void meter_task(void *unused){
    (void)unused;
    uart_config_t uart={.baud_rate=METER_BAUD,.data_bits=UART_DATA_8_BITS,.parity=UART_PARITY_DISABLE,.stop_bits=UART_STOP_BITS_1,.flow_ctrl=UART_HW_FLOWCTRL_DISABLE,.source_clk=UART_SCLK_DEFAULT};
    if(uart_param_config(METER_UART,&uart)!=ESP_OK||uart_set_pin(METER_UART,METER_TX_GPIO,METER_RX_GPIO,UART_PIN_NO_CHANGE,UART_PIN_NO_CHANGE)!=ESP_OK||uart_driver_install(METER_UART,256,0,0,NULL,0)!=ESP_OK){ESP_LOGE(TAG,"Meter UART unavailable");vTaskDelete(NULL);return;}
    nvs_handle_t store=0;bool storage=config.calibration_ready&&nvs_flash_init_partition("energy")==ESP_OK&&nvs_open_from_partition("energy","energy",NVS_READWRITE,&store)==ESP_OK;
    energy_state_t energy;energy_init(&energy,config.profile_crc);
    if(storage){uint8_t data[ENERGY_CHECKPOINT_SIZE];size_t n=sizeof(data);esp_err_t e=nvs_get_blob(store,"checkpoint",data,&n);
        if(e!=ESP_ERR_NVS_NOT_FOUND && (e!=ESP_OK||!energy_restore(&energy,data,n,config.profile_crc)))storage=false;}
    uint64_t checked_at=0,saved_at=0;bool calibrated=false;
    for(;;){
        uint64_t now=now_ms();
        if(!checked_at||now-checked_at>=60000){calibrated=profile_matches();checked_at=now;}
        uint8_t measurements[28],counters[16];meter_sample_t sample={0};
        bool online=read_registers(0x0002,measurements,sizeof(measurements))&&read_registers(0x001E,counters,sizeof(counters))&&meter_decode(measurements,counters,&sample);
        /* AC-only calibrated design. DC mode cannot silently use AC calibration. */
        bool valid=online&&calibrated&&!(sample.status&0x8000);
        if(valid&&storage)energy_observe(&energy,sample.import_raw,now,config.energy_mwh);
        else energy_mark_gap(&energy);
        if(storage&&now-saved_at>=60000){uint8_t data[ENERGY_CHECKPOINT_SIZE];energy_checkpoint(&energy,data);
            if(nvs_set_blob(store,"checkpoint",data,sizeof(data))!=ESP_OK||nvs_commit(store)!=ESP_OK)storage=false;
            saved_at=now;}
        xSemaphoreTake(state_lock,portMAX_DELAY);
        state.meter_online=online;state.calibrated=valid;state.energy_storage_ok=storage;state.energy=energy;
        if(online){state.meter=sample;state.meter_observed_ms=now;}
        xSemaphoreGive(state_lock);
        vTaskDelay(pdMS_TO_TICKS(1000));
    }
}
void app_main(void){
    /* Output latch LOW before enabling drivers; external pulldowns cover reset/boot ROM. */
    for(unsigned i=0;i<3;i++){gpio_set_level(relays[i],0);gpio_set_direction(relays[i],GPIO_MODE_OUTPUT);gpio_set_level(relays[i],0);}
    for(unsigned i=0;i<3;i++){gpio_set_direction(keys[i],GPIO_MODE_INPUT);gpio_set_pull_mode(keys[i],GPIO_PULLUP_ONLY);}
    state_lock=xSemaphoreCreateMutex();if(!state_lock){ESP_LOGE(TAG,"No control mutex; outputs remain OFF");return;}
    uint8_t random[16];char boot[33];bootloader_random_enable();esp_fill_random(random,sizeof(random));bootloader_random_disable();
    for(unsigned i=0;i<16;i++)snprintf(boot+i*2,3,"%02x",random[i]);
    switch_init(&state.control,boot);
    device_config_load(&config);
#if CONFIG_CARBENTRA_SWITCH_ALLOW_ACTUATION
    bool commissioned=config.commissioned;
#else
    bool commissioned=false;
#endif
    switch_configure(&state.control,commissioned,config.protected_mask,config.maintenance,config.manual_hold_ms);
    xTaskCreate(key_task,"local_keys",2048,NULL,8,NULL);
    xTaskCreate(meter_task,"aggregate_meter",4096,NULL,5,NULL);
    if(nvs_flash_init()!=ESP_OK){ESP_LOGE(TAG,"Wi-Fi NVS unavailable; preserved storage, local control active");return;}
    network_start(&config);
}

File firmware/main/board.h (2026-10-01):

#ifndef SWITCH_BOARD_H
#define SWITCH_BOARD_H
/* Contract with electronics: ESP32-C3-MINI-1-N4X, cold domain only. */
#define RELAY1_GPIO 0
#define RELAY2_GPIO 1
#define RELAY3_GPIO 3
#define KEY1_GPIO 4
#define KEY2_GPIO 5
#define KEY3_GPIO 6
#define METER_RX_GPIO 7
#define METER_TX_GPIO 10
#define METER_UART 1
#define METER_BAUD 9600
#endif

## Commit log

2026-10-01 Publish verified native Windows engineering source
    Verified source tree: 9b3c5c25f5e0e908e55e2ca2d958ac51077c4aee. Earlier delivery and local evolution remain in the local archive/pre-open-source-20261001 branch.
    [bom.csv, carbentra_smart_switch.blend, carbentra_smart_switch_animation.blend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]
2026-10-01 Bind release targets to current firmware validation and preserve historical assets
